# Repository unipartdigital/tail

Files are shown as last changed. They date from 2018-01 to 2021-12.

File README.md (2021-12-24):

# Tail
Tail - an indoor position system using UWB radio

# Description

Tail consists of tags, anchors and a server.

A tag is a battery-powered device which occasionally transmits a packet on UWB radio.

An anchor is an externally-powered device in a fixed location which acts as a bridge between UWB radio and the network on which the server resides.

The server sends and receives packets via the anchors, and is able to compute the location of each tag using multilateration.

A simpler mode of operation has also been developed whereby an anchor and a tag perform two-way communications to establish a distance between a tag and a single anchor.

# Status

Tail has been developed to a functional demo in a constrained test environment. It requires further development before it can be used in a production environment.

Unipart Digital is not currently developing this project past this stage.

# Video

Unipart Digital produced a video showing how the system works, and demonstrating it in action. The video is available here:

https://unipart.digital/images/projects/tail/tail-commercial.mp4

# Repositories

## tail
This repository is the monorepo that was used for the duration of the development project, so contains everything related to the tags - firmware, hardware, CAD etc,
various works on the anchor software as well as a number of scripts, utilities and other bits and pieces.

## dw1000
https://github.com/unipartdigital/dw1000

This contains hardware and drivers for a DW1000 interface card for a Raspberry Pi

## utrack-tail
https://github.com/unipartdigital/utrack-tail

This repository contains the standalone anchor code required for the two-way communications mode.

## tail-server
https://github.com/unipartdigital/tail-server

This repository contains the latest attempt at developing a multilaterating server for the one way ranging mode.

## tail-anchor-hardware
https://github.com/unipartdigital/tail-anchor-hardware

This repository contains the hardware for a standalone anchor

## tail-anchor-firmware
https://github.com/unipartdigital/tail-anchor-firmware

This repository contains the (as yet barely started) firmware for a standalone anchor

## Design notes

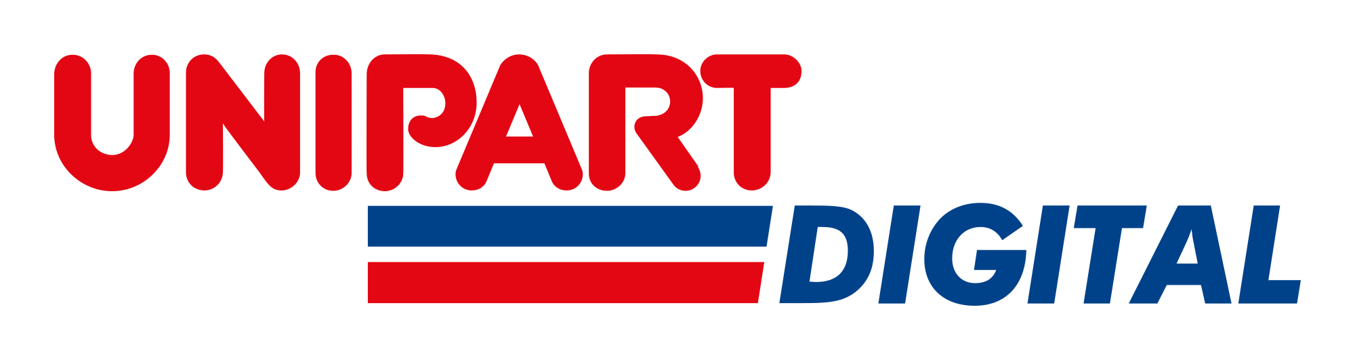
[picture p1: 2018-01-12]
circuit/v2b/Unipart_Digital_flat_RGB.png

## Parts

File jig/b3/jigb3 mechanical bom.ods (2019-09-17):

Quantity | 5
Item | Quantity per jig | Quantity total | URL
M2.5 hex nut | 8 | 40 | https://www.westfieldfasteners.co.uk/Metric-Nuts/Hex-Nut-M2.5-A2-Stainless.html
M2.5 screw 6mm | 8 | 40 | https://www.westfieldfasteners.co.uk/Bolts-Screws-Metric/Hex-Bolt-Full-Thread-M2.5x6-A2-Stainless.html
M2.5 dowel pin 20mm | 4 | 20 | https://www.westfieldfasteners.co.uk/Pins-and-Clips/Parallel-Pin-Dowel-Pin-2.5x20-A1-Stainless-Steel.html
M3 dowel pin 12mm | 2 | 10 | https://www.westfieldfasteners.co.uk/Pins-and-Clips/Parallel-Pin-Dowel-Pin-3x12-A1-Stainless-Steel.html

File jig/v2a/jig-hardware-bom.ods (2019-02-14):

Tail tag v2a jig BOM | Quantity | 10
Item | Quantity per jig | Quantity total | Supplier | Price | Price per | MOQ | Total price | Description
Jig PCB | 1 | 10 | GOC |  | 1 | 1 | 0
Pogo pins | 19 | 190 | Farnell | 1.75 | 1 | 1 | 332.5 | https://uk.farnell.com/harwin/p13-0123/probe-pointed-1-27mm-pitch/dp/9960104?ost=9960104
Toggle clamp GH-201B | 1 | 10 |  | 9.66 | 1 | 1 | 96.6 | https://www.goodhanduk.co.uk/Catalogue/Toggle-Clamps/Horizontal-Toggle-Clamps/Horizontal-Toggle-Clamp-Flat-Base-All-Arm-Types/Horizontal-Toggle-Clamp-Size-90K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 | Alternative with different dimensions: https://www.amazon.co.uk/IMAGINE-Holding-CapacityAntislip-Horizontal-Release/dp/B073Z9ZVGQ
8mm M2.5 screw | 8 | 80 |  | 2.28 | 80 | 80 | 2.28 | https://www.westfieldfasteners.co.uk/Bolts-Screws-Metric/Machine-Screw-Phillips-Pan-M2.5x8-A2-Stainless.html
M2.5 hex nut | 8 | 80 |  | 2.99 | 150 | 150 | 2.99 | https://www.westfieldfasteners.co.uk/Metric-Nuts/Hex-Nut-M2.5-A2-Stainless.html
M2.5 square nut | 4 | 40 |  | 0.1 | 1 | 1 | 4 | https://www.accu.co.uk/en/flat-square-nuts/21325-HFSN-M2-5-A2
12mm M5 bolt | 4 | 40 |  | 3.14 | 30 | 30 | 6.28 | https://www.westfieldfasteners.co.uk/Bolts-Screws-Metric/Machine-Screw-Phillips-Pan-M5x12-A2-Stainless.html
M5 square nut | 4 | 40 |  | 2.3 | 40 | 40 | 2.3 | https://www.westfieldfasteners.co.uk/Metric-Nuts/Square-Thin-Nut-M5-A2-Stainless.html
Total |  |  |  | 44.695 |  |  | 446.95

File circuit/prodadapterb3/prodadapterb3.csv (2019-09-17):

Source: | /home/gavan/Nextcloud/unipart/git/tail/circuit/prodadapterb3/prodadapterb3.sch
Date: | Tue 17 Sep 2019 14:27:01 BST
Tool: | Eeschema 4.0.7-e2-6376~61~ubuntu18.04.1
Generator: | /usr/lib/kicad/plugins/bom_csv_grouped_by_value.py
Component Count: | 8
Individual Components:
Item | Qty | Reference(s) | Value | LibPart | Footprint | Datasheet | MFR | MPN | SPN | SPR
 |  | J1 | Conn_02x20_Odd_Even | conn:Conn_02x20_Odd_Even | Pin_Headers:Pin_Header_Angled_2x20_Pitch2.54mm |  | Harting | 09 18 540 6903 | 1096897 | Farnell
 |  | J2 | Conn_02x05_Odd_Even | conn:Conn_02x05_Odd_Even | Pin_Headers:Pin_Header_Angled_2x05_Pitch1.27mm |  | Samtec | FTSH-105-01-L-D-RA-K | 2856878 | Farnell
 |  | J3 | Conn_01x02 | conn:Conn_01x02 | Pin_Headers:Pin_Header_Straight_1x02_Pitch2.54mm |  | Multicomp | 2211S-02G | 1593411 | Farnell
 |  | J4 | Conn_02x20_Odd_Even | conn:Conn_02x20_Odd_Even | Pin_Headers:Pin_Header_Angled_2x20_Pitch2.54mm |  | Harting | 09 18 540 6903 | 1096897 | Farnell
 |  | R1 | 3K9 | device:R | Resistors_THT:R_Axial_DIN0204_L3.6mm_D1.6mm_P5.08mm_Horizontal |  | Multicomp | MF12 3K9 | 9343156 | Farnell
 |  | R2 | 3K9 | device:R | Resistors_THT:R_Axial_DIN0204_L3.6mm_D1.6mm_P5.08mm_Horizontal |  | Multicomp | MF12 3K9 | 9343156 | Farnell
 |  | R3 | 3K9 | device:R | Resistors_THT:R_Axial_DIN0204_L3.6mm_D1.6mm_P5.08mm_Horizontal |  | Multicomp | MF12 3K9 | 9343156 | Farnell
 |  | U1 | 24LC128 | memory:24LC128 | Housings_DIP:DIP-8_W7.62mm |  | Microchip | 24LC128-I/P | 9757929 | Farnell
Collated Components:
Item | Qty | Reference(s) | Value | LibPart | Footprint | Datasheet | MFR | MPN | SPN | SPR
1 | 2 | J1, J4 | Conn_02x20_Odd_Even | conn:Conn_02x20_Odd_Even | Pin_Headers:Pin_Header_Angled_2x20_Pitch2.54mm |  | Harting | 09 18 540 6903 | 1096897 | Farnell
2 | 1 | J2 | Conn_02x05_Odd_Even | conn:Conn_02x05_Odd_Even | Pin_Headers:Pin_Header_Angled_2x05_Pitch1.27mm |  | Samtec | FTSH-105-01-L-D-RA-K | 2856878 | Farnell
3 | 1 | J3 | Conn_01x02 | conn:Conn_01x02 | Pin_Headers:Pin_Header_Straight_1x02_Pitch2.54mm |  | Multicomp | 2211S-02G | 1593411 | Farnell
4 | 3 | R1, R2, R3 | 3K9 | device:R | Resistors_THT:R_Axial_DIN0204_L3.6mm_D1.6mm_P5.08mm_Horizontal |  | Multicomp | MF12 3K9 | 9343156 | Farnell
5 | 1 | U1 | 24LC128 | memory:24LC128 | Housings_DIP:DIP-8_W7.62mm |  | Microchip | 24LC128-I/P | 9757929 | Farnell

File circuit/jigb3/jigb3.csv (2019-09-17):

Source: | /home/gavan/Nextcloud/unipart/git/tail/circuit/jigb3/jigb3.sch
Date: | Tue 17 Sep 2019 14:27:17 BST
Tool: | Eeschema 4.0.7-e2-6376~61~ubuntu18.04.1
Generator: | /usr/lib/kicad/plugins/bom_csv_grouped_by_value.py
Component Count: | 16
Individual Components:
Item | Qty | Reference(s) | Value | LibPart | Footprint | Datasheet | MFR | MPN | SPN | SPR
 |  | C1 | 2.2u | device:C_Small | Capacitors_THT:CP_Radial_D5.0mm_P2.00mm |  | Multicomp | MCRH100V225M5X11 | 1902943 | Farnell
 |  | C2 | 100n | device:C_Small | Capacitors_THT:C_Disc_D5.0mm_W2.5mm_P5.00mm |  | Vishay | K104K15X7RF53H5 | 1141777 | Farnell
 |  | C3 | 2.2u | device:C_Small | Capacitors_THT:CP_Radial_D5.0mm_P2.00mm |  | Multicomp | MCRH100V225M5X11 | 1902943 | Farnell
 |  | J1 | Conn_01x05 | conn:Conn_01x05 | Pin_Headers:Pin_Header_Angled_1x05_Pitch2.54mm |  | Wurth | 61300511021 | 2356179 | Farnell
 |  | J2 | Conn_01x05 | conn:Conn_01x05 | Pin_Headers:Pin_Header_Angled_1x05_Pitch2.54mm |  | Wurth | 61300511021 | 2356179 | Farnell
 |  | J3 | Conn_01x03 | conn:Conn_01x03 | Pin_Headers:Pin_Header_Angled_1x03_Pitch2.54mm |  | Wurth | 61300311021 | 2356177 | Farnell
 |  | J4 | Conn_02x05_Odd_Even | conn:Conn_02x05_Odd_Even | Pin_Headers:Pin_Header_Angled_2x05_Pitch1.27mm |  | Samtec | FTSH-105-01-L-D-RA-K | 2856878 | Farnell
 |  | J5 | Conn_01x01 | conn:Conn_01x01 | jigb3:P70-2200045 |  | Harwin | P70-2200045 | 2664890 | Farnell
 |  | J6 | Conn_01x01 | conn:Conn_01x01 | jigb3:P70-2200045 |  | Harwin | P70-2200045 | 2664890 | Farnell
 |  | J7 | Conn_01x01 | conn:Conn_01x01 | jigb3:P70-2200045 |  | Harwin | P70-2200045 | 2664890 | Farnell
 |  | J8 | Conn_01x01 | conn:Conn_01x01 | jigb3:P70-2200045 |  | Harwin | P70-2200045 | 2664890 | Farnell
 |  | J9 | Conn_01x01 | conn:Conn_01x01 | jigb3:P70-2200045 |  | Harwin | P70-2200045 | 2664890 | Farnell
 |  | J10 | Conn_01x01 | conn:Conn_01x01 | jigb3:P70-2200045 |  | Harwin | P70-2200045 | 2664890 | Farnell
 |  | J11 | Conn_02x20_Odd_Even | conn:Conn_02x20_Odd_Even | Pin_Headers:Pin_Header_Straight_2x20_Pitch2.54mm |  | Multicomp | 2213S-40G | 2725179 | Farnell
 |  | R1 | 100K | device:R | Resistors_THT:R_Axial_DIN0204_L3.6mm_D1.6mm_P5.08mm_Horizontal |  | Multicomp | MF12 100K | 9342427 | Farnell
 |  | U1 | MAX882 | regul:MAX882 | Housings_DIP:DIP-8_W7.62mm |  | Maxim | MAX882CPA+ | 2517079 | Farnell
Collated Components:
Item | Qty | Reference(s) | Value | LibPart | Footprint | Datasheet | MFR | MPN | SPN | SPR
1 | 2 | C1, C3 | 2.2u | device:C_Small | Capacitors_THT:CP_Radial_D5.0mm_P2.00mm |  | Multicomp | MCRH100V225M5X11 | 1902943 | Farnell
2 | 1 | C2 | 100n | device:C_Small | Capacitors_THT:C_Disc_D5.0mm_W2.5mm_P5.00mm |  | Vishay | K104K15X7RF53H5 | 1141777 | Farnell
3 | 2 | J1, J2 | Conn_01x05 | conn:Conn_01x05 | Pin_Headers:Pin_Header_Angled_1x05_Pitch2.54mm |  | Wurth | 61300511021 | 2356179 | Farnell
4 | 1 | J3 | Conn_01x03 | conn:Conn_01x03 | Pin_Headers:Pin_Header_Angled_1x03_Pitch2.54mm |  | Wurth | 61300311021 | 2356177 | Farnell
5 | 1 | J4 | Conn_02x05_Odd_Even | conn:Conn_02x05_Odd_Even | Pin_Headers:Pin_Header_Angled_2x05_Pitch1.27mm |  | Samtec | FTSH-105-01-L-D-RA-K | 2856878 | Farnell
6 | 6 | J5, J6, J7, J8, J9, J10 | Conn_01x01 | conn:Conn_01x01 | jigb3:P70-2200045 |  | Harwin | P70-2200045 | 2664890 | Farnell
7 | 1 | J11 | Conn_02x20_Odd_Even | conn:Conn_02x20_Odd_Even | Pin_Headers:Pin_Header_Straight_2x20_Pitch2.54mm |  | Multicomp | 2213S-40G | 2725179 | Farnell
8 | 1 | R1 | 100K | device:R | Resistors_THT:R_Axial_DIN0204_L3.6mm_D1.6mm_P5.08mm_Horizontal |  | Multicomp | MF12 100K | 9342427 | Farnell
9 | 1 | U1 | MAX882 | regul:MAX882 | Housings_DIP:DIP-8_W7.62mm |  | Maxim | MAX882CPA+ | 2517079 | Farnell

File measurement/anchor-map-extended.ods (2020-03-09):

 | 1 | 2 | 3 | 4 | 5 | 6 | 7 | 8 | 9 | 10 | 11 | 12 | 13 | 14 | 15
1 | x | - | - | - | - | - | - | - | - | - | 324 | 395 | 557 | 740 | 935
2 | x | x | - | - | - | - | - | - | - | - | 386 | 291 | 309 | 438 | 614
3 | x | x | x | - | - | - | - | - | - | -
4 | x | x | x | x | - | - | - | - | - | - | 753 | 588 | 400 | 250 | 234
5 | x | x | x | x | x | - | - | - | - | -
6 | x | x | x | x | x | x | - | - | - | -
7 | x | x | x | x | x | x | x | - | - | - | 312 | 357 | 486 | 664 | 855
8 | x | x | x | x | x | x | x | x | - | -
9 | x | x | x | x | x | x | x | x | x | - | 559 | 411 | 277 | 282 | 413
10 | x | x | x | x | x | x | x | x | x | x | 893 | 728 | 525 | 340 | 211
11 | x | x | x | x | x | x | x | x | x | x | x
12 | x | x | x | x | x | x | x | x | x | x | x | x
13 | x | x | x | x | x | x | x | x | x | x | x | x | x
14 | x | x | x | x | x | x | x | x | x | x | x | x | x | x
15 | x | x | x | x | x | x | x | x | x | x | x | x | x | x | x
Z |  |  |  |  |  |  |  |  |  |  | 4.7 | 4.7 | 4.7 | 4.7 | 4.7
 | X | Y | Z
11 | 0.33489371 | 3.13808962 | -0.047
12 | 2.06095082 | 2.96326638 | -0.047
13 | 4.16335929 | 2.62943822 | -0.047
14 | 6.26712033 | 2.38474151 | -0.047
15 | 8.35542711 | 2.12059253 | -0.047

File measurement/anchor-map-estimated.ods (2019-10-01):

0 | 632.03924831 | 32 | 1 |  | 1 | 2 | 3 | 4 | 5 | 6 | 7 | 8 | 9 | 10
329.55736086 | 557.70306928 | 33 | 2 (top) | 1 | x | 337.83860290054 | 350.682878451111 | 800.550696320505 | 1030.33437301795 | 507.674512944963 | 632.093616925006 | 803.938136224154 | 800.040606772778 | 1074.35830753595
329.94077707 | 557.09443618 | 124.2 | 3 (bottom) | 2 | x | x | 91.2028368102687 | 462.917088328823 | 711.515809491833 | 542.535538862879 | 643.748108199432 | 666.542603932412 | 583.294673321986 | 774.496596643959
776.03914733 | 435.45743534 | 31.5 | 4 | 3 | x | x | x | 471.585205367999 | 704.957560625813 | 534.565046775072 | 650.264912876859 | 660.185648927858 | 589.577311100258 | 779.208388487231
907.27560286 | 152.55813223 | 124.4 | 5 | 4 | x | x | x | x | 325.400419422289 | 833.719350411966 | 882.858855017837 | 715.212634128539 | 527.945932798777 | 440.341330083461
4.73432517999999 | 132.82971589 | 124.2 | 6 | 5 | x | x | x | x | x | 902.756893259493 | 916.951593112388 | 646.259779620162 | 460.117212571123 | 176.38796414993
8.04544299999998 | 0 | 30 | 7 | 6 | x | x | x | x | x | x | 162.875218878244 | 388.591550769894 | 507.145152883847 | 882.332637271155
313.65290155 | -102.87988617 | 120.5 | 8 | 7 | x | x | x | x | x | x | x | 334.918556816045 | 476.438345385502 | 865.045208041609
484.44593583 | -4.65052524 | 33.8 | 9 | 8 | x | x | x | x | x | x | x | x | 215.258351538995 | 576.653727452348
873.0666435 | 5.94008765 | 32.5 | 10 | 9 | x | x | x | x | x | x | x | x | x | 388.767161050567
 |  |  |  | 10 | x | x | x | x | x | x | x | x | x | x
 |  |  |  |  | 1 | 2 | 3 | 4 | 5 | 6 | 7 | 8 | 9 | 10
 |  |  |  | 1 | x | 338 | 351 | 800 | 1030 | 507 | 632 | 804 | 800 | 1075
 |  |  |  | 2 | x | x | 91 | 463 | 712 | 542 | 644 | 667 | 583 | 774
 |  |  |  | 3 | x | x | x | 472 | 705 | 535 | 650 | 660 | 590 | 779
 |  |  |  | 4 | x | x | x | x | 325 | 834 | 883 | 715 | 351 | 440
 |  |  |  | 5 | x | x | x | x | x | 903 | 917 | 646 | 460 | 176
 |  |  |  | 6 | x | x | x | x | x | x | 162 | 388 | 507 | 882
 |  |  |  | 7 | x | x | x | x | x | x | x | ************** | 476 | 865
 |  |  |  | 8 | x | x | x | x | x | x | x | x | 316 | 577
 |  |  |  | 9 | x | x | x | x | x | x | x | x | x | 388
 |  |  |  | 10 | x | x | x | x | x | x | x | x | x | x
 |  |  |  | cm | 1 | 2 | 3 | 4 | 5 | 6 | 7 | 8 | 9 | 10
 |  |  |  | 1 | x | 0.16139709946043 | 0.317121548889418 | -0.55069632050504 | -0.334373017953112 | -0.674512944962601 | -0.09361692500579 | 0.061863775846064 | -0.040606772777892 | 0.641692464049129
 |  |  |  | 2 | x | x | -0.202836810268721 | 0.082911671177215 | 0.484190508166535 | -0.53553886287898 | 0.251891800567819 | 0.457396067588093 | -0.294673321985556 | -0.49659664395881
 |  |  |  | 3 | x | x | x | 0.414794632000564 | 0.042439374187325 | 0.434953224928108 | -0.264912876859057 | -0.185648927857756 | 0.422688899742298 | -0.20838848723065
 |  |  |  | 4 | x | x | x | x | -0.400419422288564 | 0.280649588033612 | 0.141144982163155 | -0.212634128539207 | -176.945932798777 | -0.34133008346123
 |  |  |  | 5 | x | x | x | x | x | 0.243106740507301 | 0.048406887611577 | -0.259779620161794 | -0.117212571123446 | -0.387964149929985
 |  |  |  | 6 | x | x | x | x | x | x | -0.875218878244453 | -0.591550769894013 | -0.145152883846606 | -0.332637271154908
 |  |  |  | 7 | x | x | x | x | x | x | x | ************** | -0.438345385501918 | -0.045208041609271
 |  |  |  | 8 | x | x | x | x | x | x | x | x | 100.741648461005 | 0.34627254765212
 |  |  |  | 9 | x | x | x | x | x | x | x | x | x | -0.767161050566983
 |  |  |  | 10 | x | x | x | x | x | x | x | x | x | x
 |  |  |  |  |  |  |  |  | Original estimates |  |  | Removed 4/9 |  |  | Removed 4/9 and 7/9 |  | Normalised
 |  |  |  |  |  |  |  |  | -549.92060933 | 554.79006164 |  | -453.53371699 | 673.8855102 |  | -485.77448252 | 630.85439371 | 0 | 632.03924831
 |  |  |  |  |  |  |  |  | -216.69719363 | 509.12302366 |  | -129.39312323 | 579.41924456 |  | -156.21712166 | 556.51821468 | 329.55736086 | 557.70306928
 |  |  |  |  |  |  |  |  | -216.28381488 | 508.53831533 |  | -129.0531305 | 578.78592534 |  | -155.83370545 | 555.90958158 | 329.94077707 | 557.09443618
 |  |  |  |  |  |  |  |  | 239.01845486 | 399.2983762 |  | 308.55206086 | 428.17610248 |  | 290.26466481 | 434.27258074 | 776.03914733 | 435.45743534
 |  |  |  |  |  |  |  |  | 394.45296138 | 152.2766373 |  | 422.31680235 | 139.00937021 |  | 421.50112034 | 151.37327763 | 907.27560286 | 152.55813223
 |  |  |  |  |  |  |  |  | -503.95725213 | 53.99389318 |  | -479.57394355 | 174.9388591 |  | -481.04015734 | 131.64486129 | 4.73432517999999 | 132.82971589
 |  |  |  |  |  |  |  |  | -488.90319769 | -77.97627345 |  | -484.17633545 | 41.92596162 |  | -477.72903952 | -1.1848546 | 8.04544299999998 | 0
 |  |  |  |  |  |  |  |  | -184.45730836 | -156.03790622 |  | -190.33885462 | -79.95536936 |  | -172.12158097 | -104.06474077 | 313.65290155 | -102.87988617
 |  |  |  |  |  |  |  |  | 11.95845782 | -2.52522182 |  | -2.44477591 | 13.47578202 |  | -1.32854669 | -5.83537984 | 484.44593583 | -4.65052524
 |  |  |  |  |  |  |  |  | 371.10605914 | -0.83738859 |  | 378.88551441 | -5.52773253 |  | 387.29216098 | 4.75523305 | 873.0666435 | 5.94008765

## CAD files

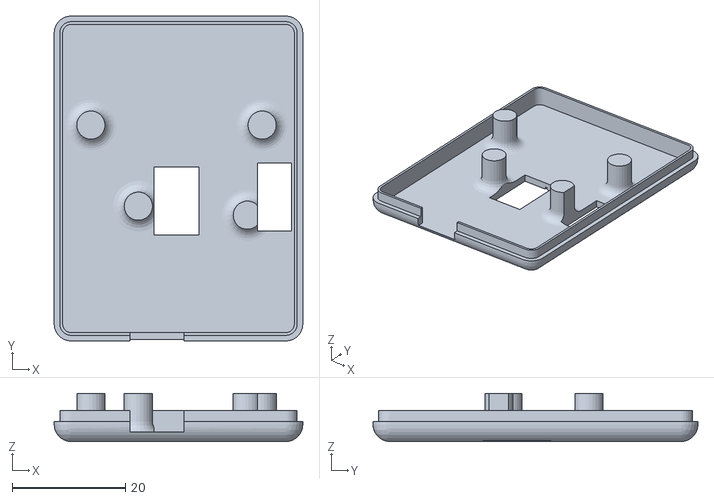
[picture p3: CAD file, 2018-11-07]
case/v2/case-lid.stl
44.0 x 57.5 x 8.50

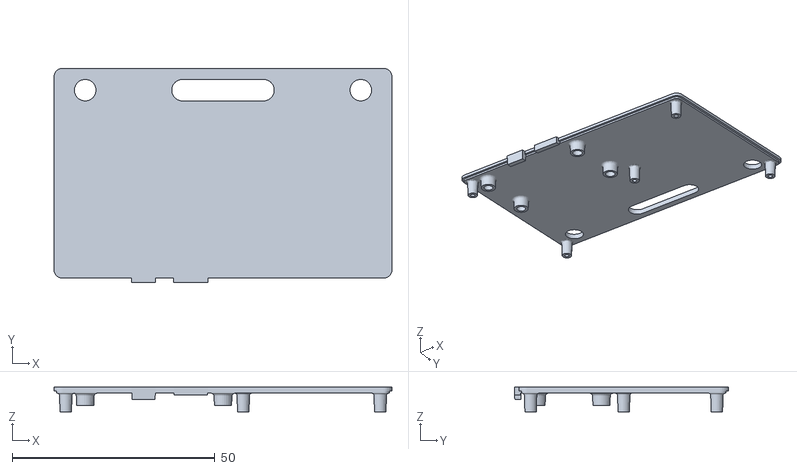
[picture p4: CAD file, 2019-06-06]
case/v2a/case-lid-lip2.stl
83.4 x 52.9 x 6.10

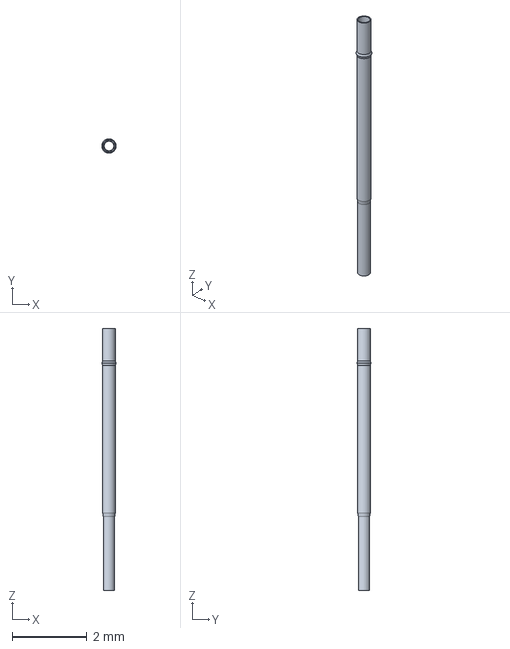
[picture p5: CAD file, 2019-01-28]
circuit/jig2a/s13-503.fcstd
0.382 x 0.382 x 6.99 mm

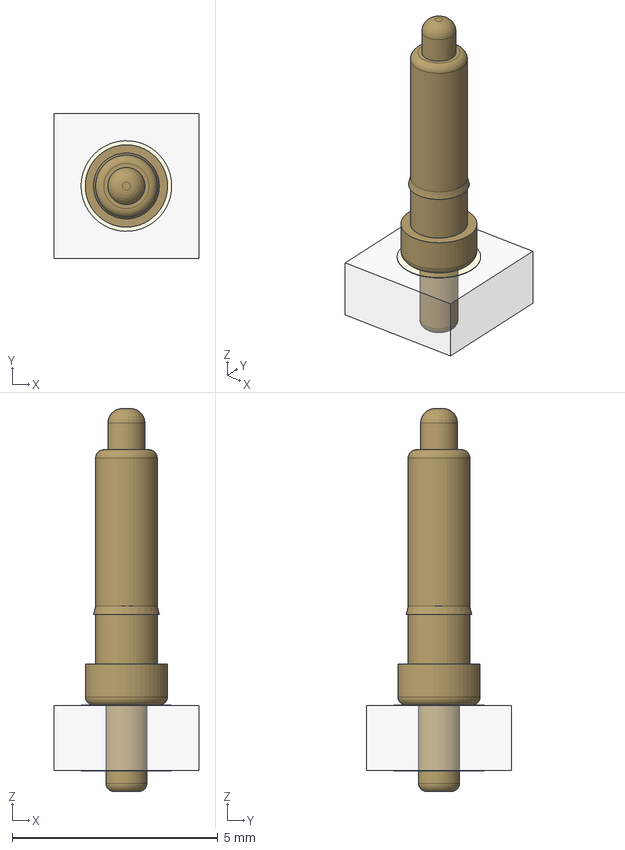
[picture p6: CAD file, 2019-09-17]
circuit/jigb3/pogopin.FCStd
3.51 x 3.52 x 9.30 mm
TopPads
BotPads
PTHs
Pcb

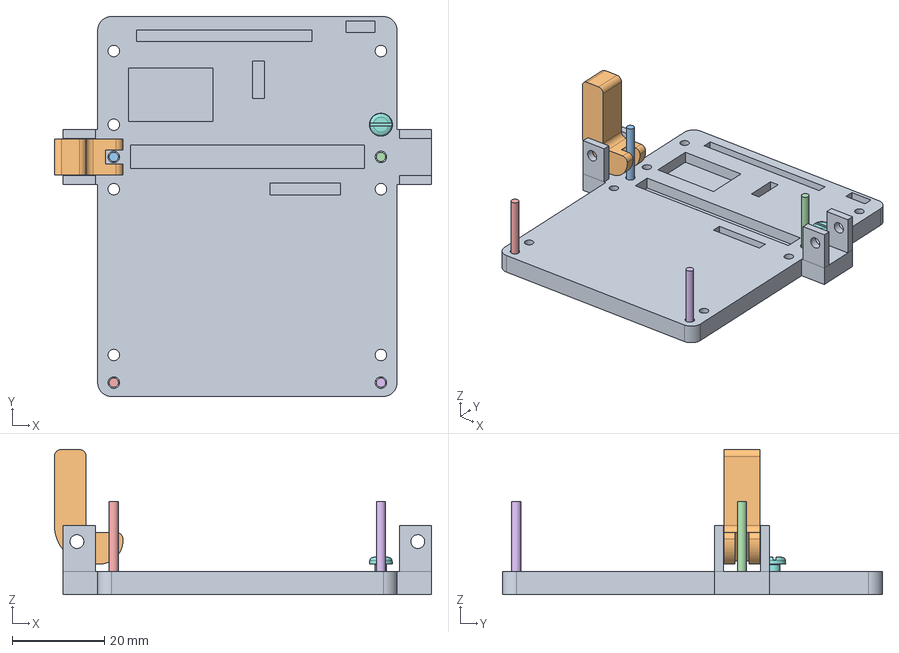
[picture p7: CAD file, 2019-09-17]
jig/b3/b3jig.FCStd
81.9 x 82.5 x 31.5 mm
JigBody
LeftLever
M2.5x20.0-ScrewTap
M2.5x20.0-ScrewTap004
M2.5x20.0-ScrewTap006
M2.5x20.0-ScrewTap007
M2.5-Nut
M2.5x6-Screw

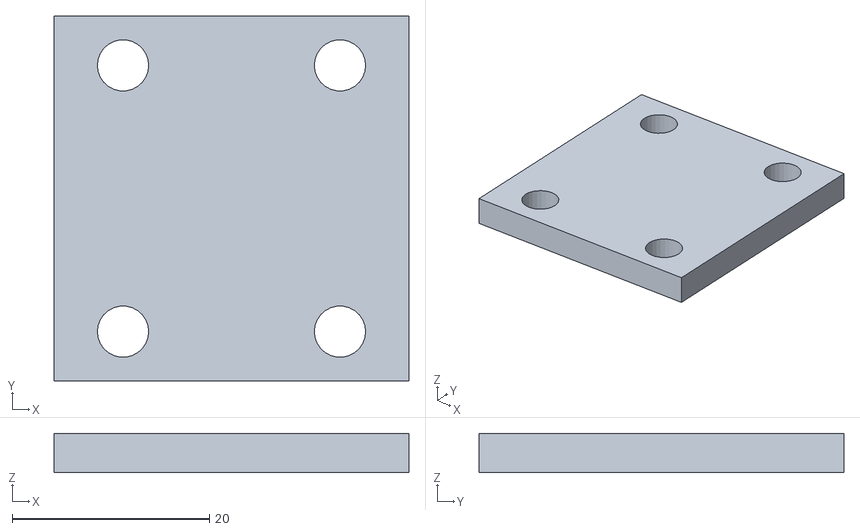
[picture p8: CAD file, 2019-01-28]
jig/v2a/jig-spacer.stl
36.0 x 37.0 x 4.00

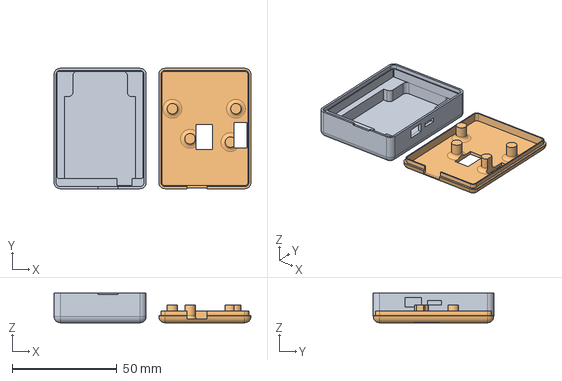
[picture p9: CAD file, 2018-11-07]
case/v2/case.fcstd
94.0 x 57.5 x 14.1 mm
Lid

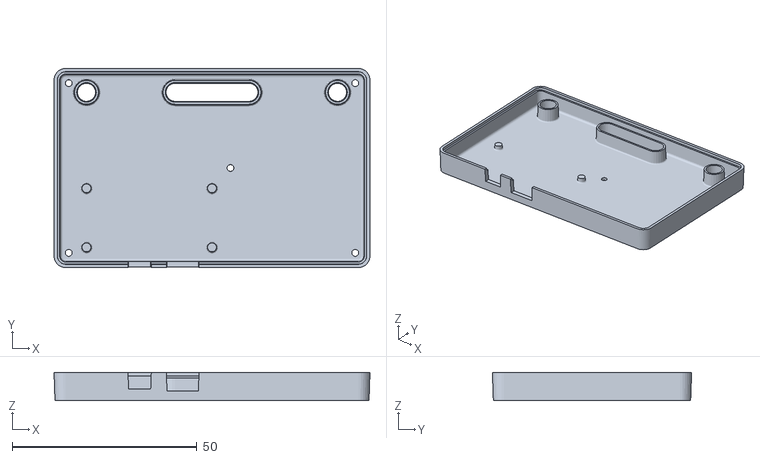
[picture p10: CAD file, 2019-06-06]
case/v2a/case-base-lip2.stl
85.6 x 54.0 x 7.60

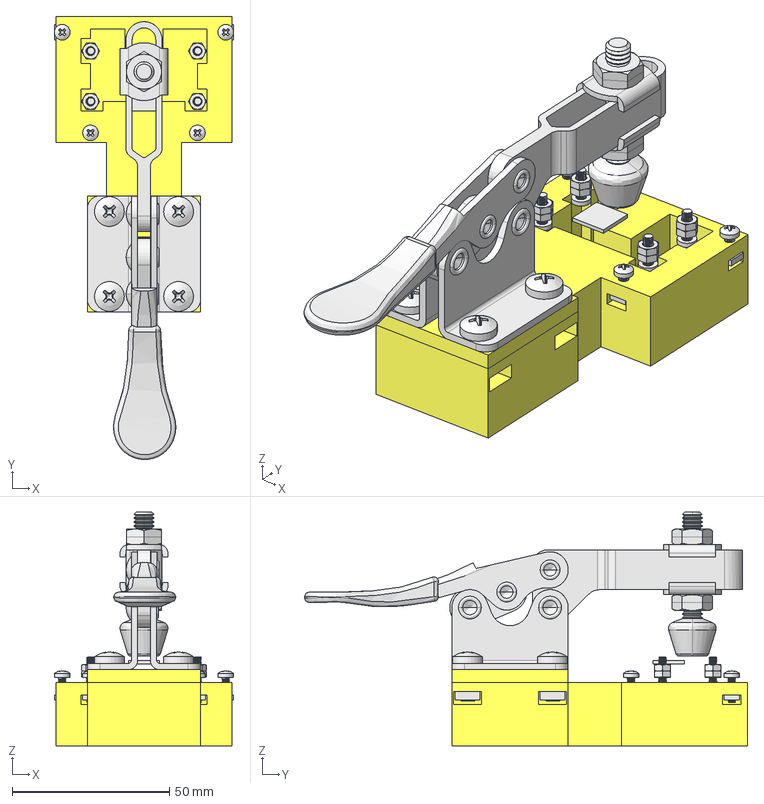
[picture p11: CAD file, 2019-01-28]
jig/v2a/jig.fcstd
57.0 x 140.8 x 74.4 mm
ClampCompound
M2.5x8-Screw230
M2.5x8-Screw
M2.5x8-Screw229
M2.5x8-Screw228
M2.5x8-Screw231
M2.5x8-Screw226
M2.5x8-Screw227
M2.5x8-Screw232
M2.5-Nut278
M2.5-Nut276
M2.5-Nut277
M2.5-Nut279
M2.5-Nut284
M2.5-Nut282
M2.5-Nut274
M2.5-Nut281
M2.5-Nut280
M2.5-Nut283
M2.5-Nut275
M2.5-Nut
M5x12-Screw412
M5x12-Screw
M5x12-Screw413
M5x12-Screw411
M5-Nut
M5-Nut350
M5-Nut349
M5-Nut348
ClampSpacer
TailCube

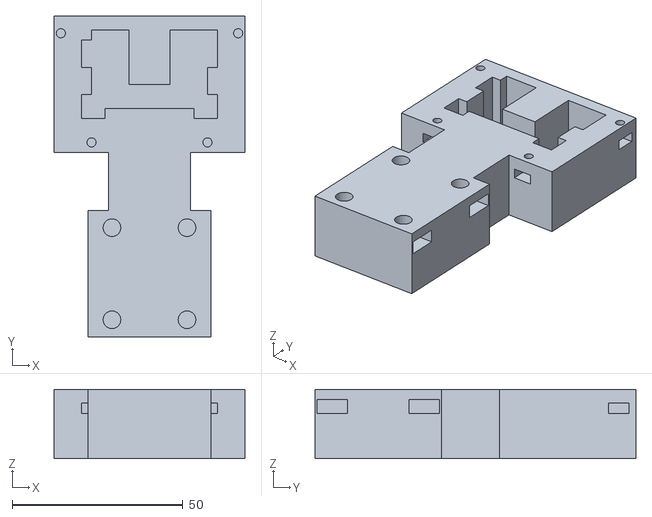
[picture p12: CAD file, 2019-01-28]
jig/v2a/jig-body.stl
56.0 x 94.0 x 20.2

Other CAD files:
case/v2/tail-logo-simplified-scaled.dxf
case/v2a/case.FCStd
case/v2/case.stl

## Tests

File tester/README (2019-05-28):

Things to install:

sudo apt install libgles2-mesa-dev

sudo -H pip3 install cython
sudo -H pip3 install kivy
sudo -H pip3 install InstrumentKit
sudo -H pip3 install gpiozero
sudo -H pip3 install netaddr

sudo apt isntall libsdl1.2-dev

sudo apt-get install libsdl2-dev libsdl2-image-dev libsdl2-mixer-dev libsdl2-ttf-dev \
   pkg-config libgl1-mesa-dev libgles2-mesa-dev \
   python-setuptools libgstreamer1.0-dev git-core \
   gstreamer1.0-plugins-{bad,base,good,ugly} \
   gstreamer1.0-{omx,alsa} python-dev libmtdev-dev \
   xclip xsel

sudo apt-get update&&sudo apt-get install libsdl-dev libsdl-image1.2-dev libsdl-mixer1.2-dev libsdl-ttf2.0-dev 
sudo apt-get install libsmpeg-dev libportmidi-dev libavformat-dev libswscale-dev
sudo apt-get install python3-dev python3-numpy

sudo -H pip3 install pygame

sudo -H pip3 install pigpio

#sudo apt install openocd

# Raspbian Stretch has too old an openocd. We need at least 0.10.0.

sudo apt install debhelper libftdi1-dev libusb-1.0-0-dev libusb-dev
sudo apt install texinfo texlive libhidapi-dev
sudo apt install libjim-dev pkg-config

# Now download and untar openocd-0.10.0

cd openocd-0.10.0
./configure -disable-werror \
	--disable-internal-jimtcl \
	--disable-internal-libjaylink \
	\
	--enable-dummy \
	--enable-ep93xx \
	--enable-at91rm9200 \
	--enable-usbprog \
	--enable-vsllink \
	--enable-rlink \
	--enable-ulink \
	--enable-arm-jtag-ew \
	--enable-buspirate \
	--enable-osbdm \
	--enable-opendous \
	--enable-remote-bitbang \
	--enable-bcm2835gpio \
	--enable-sysfsgpio \
	--enable-parport \
	--enable-parport_ppdev \
	--enable-gw16012 \
	--enable-amtjtagaccel \
	--enable-ftdi \
	--enable-stlink \
	--enable-ti-icdi

make
sudo make install

udev things for serial ports
sudo cp tail-tester.rules /etc/udev/rules.d
sudo udevadm control --reload

mkdir ~/firmware

Put some files in the directory

Add to [input] section of .kivy/config.ini

mouse = mouse
mtdev_%(name)s = probesysfs,provider=mtdev
hid_%(name)s = probesysfs,provider=hidinput

Create tester.ini:

[Tester]
FrequencyCounter: /dev/ttyStf930
Multimeter:       /dev/ttySgdm8341
GPSDO:            /dev/hidraw-gpsdo

Disable lightdm otherwise touch screen presses also end up in X, which
randomly launches unrelated applications while you're not looking

Depending on how you're starting the tester, you may want to do this permanently.

sudo systemctl stop lightdm
sudo systemctl disable lightdm

If you want a desktop icon that will launch the tester:

cp tester.desktop ~/Desktop/

Remove console/serial0,115200 from /boot/cmdline.txt
Use raspi-config to enable the serial port but disable a login prompt on the serial port

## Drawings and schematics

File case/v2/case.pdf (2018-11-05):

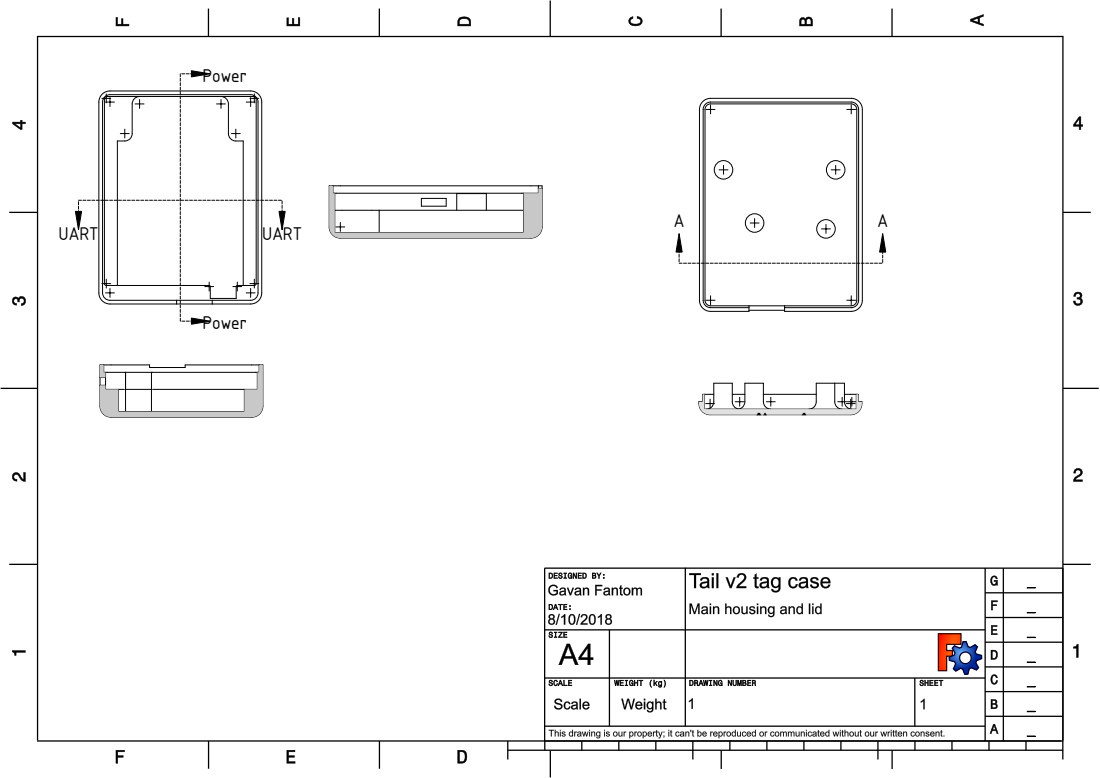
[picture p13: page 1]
er Power

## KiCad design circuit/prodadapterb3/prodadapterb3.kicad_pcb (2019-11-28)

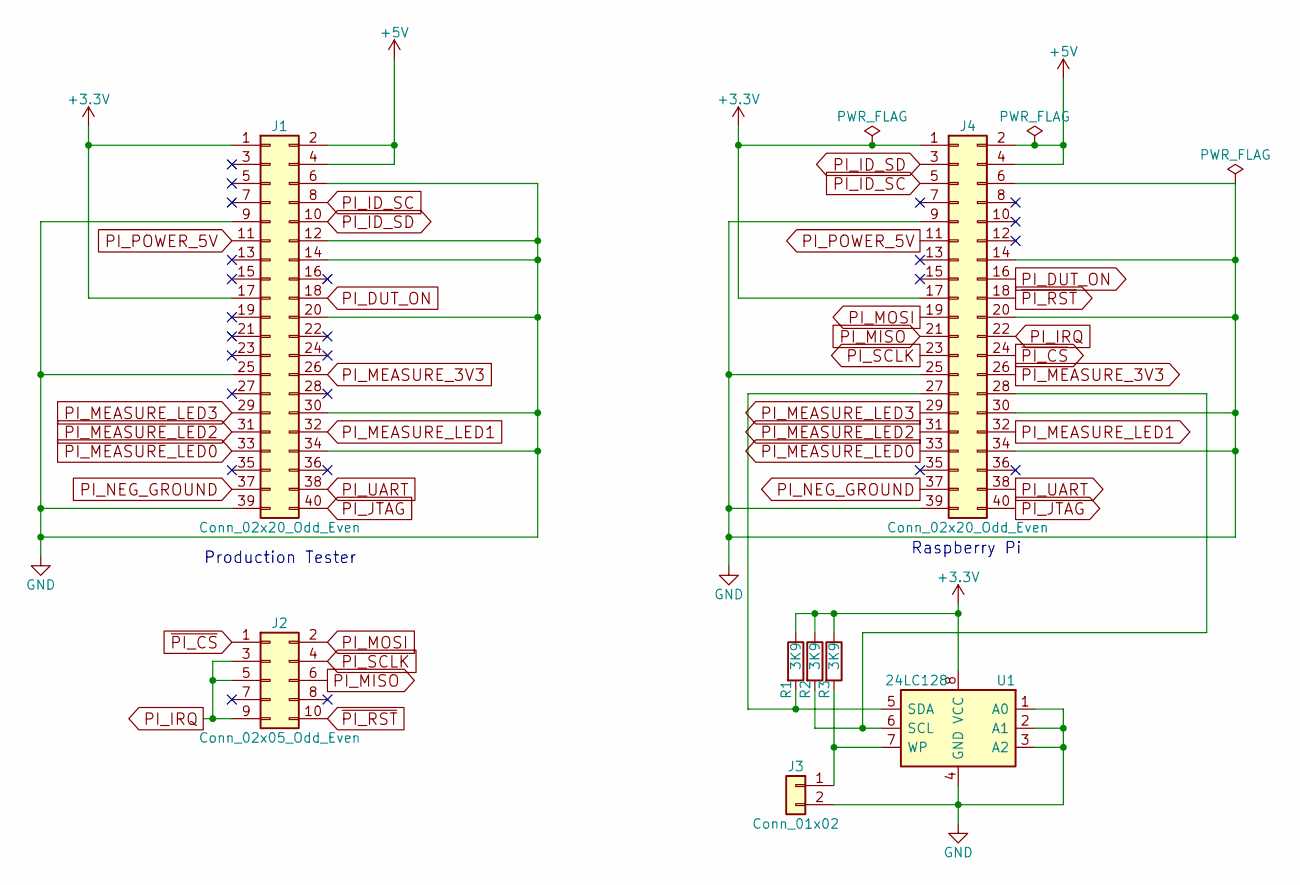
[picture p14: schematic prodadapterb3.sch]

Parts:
J1, J4: Conn_02x20_Odd_Even; Pin_Header_Angled_2x20_Pitch2.54mm; MPN 09 18 540 6903
J2: Conn_02x05_Odd_Even; Pin_Header_Angled_2x05_Pitch1.27mm; MPN FTSH-105-01-L-D-RA-K
J3: Conn_01x02; Pin_Header_Straight_1x02_Pitch2.54mm; MPN 2211S-02G
R1, R2, R3: 3K9; R_Axial_DIN0204_L3.6mm_D1.6mm_P5.08mm_Horizontal; MPN MF12 3K9
U1: 24LC128; DIP-8_W7.62mm; MPN 24LC128-I/P

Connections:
+3V3: J1.1, J1.17, J4.1, J4.17, R1.1, R2.1, R3.1, U1.8 (VCC)
+5V: J1.2, J1.4, J4.2, J4.4
GND: J1.6, J1.9, J1.12, J1.14, J1.20, J1.25, J1.30, J1.34, J1.39, J3.2, J4.6, J4.9, J4.14, J4.20, J4.25, J4.30, J4.34, J4.39, U1.1 (A0), U1.2 (A1), U1.3 (A2), U1.4 (GND)
unnamed: J3.1, R3.2, U1.7 (WP)
unnamed: J4.27, R1.2, U1.5 (SDA)
unnamed: J4.28, R2.2, U1.6 (SCL)
PI_DUT_ON: J1.18, J4.16
PI_ID_SC: J1.8, J4.5
PI_ID_SD: J1.10, J4.3
PI_IRQ: J2.3, J2.5, J2.9, J4.22
PI_JTAG: J1.40, J4.40
PI_MEASURE_3V3: J1.26, J4.26
PI_MEASURE_LED0: J1.33, J4.33
PI_MEASURE_LED1: J1.32, J4.32
PI_MEASURE_LED2: J1.31, J4.31
PI_MEASURE_LED3: J1.29, J4.29
PI_MISO: J2.6, J4.21
PI_MOSI: J2.2, J4.19
PI_NEG_GROUND: J1.37, J4.37
PI_POWER_5V: J1.11, J4.11
PI_SCLK: J2.4, J4.23
PI_UART: J1.38, J4.38
~PI_CS: J2.1, J4.24
~PI_RST: J2.10, J4.18

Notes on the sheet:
Raspberry Pi
Production Tester

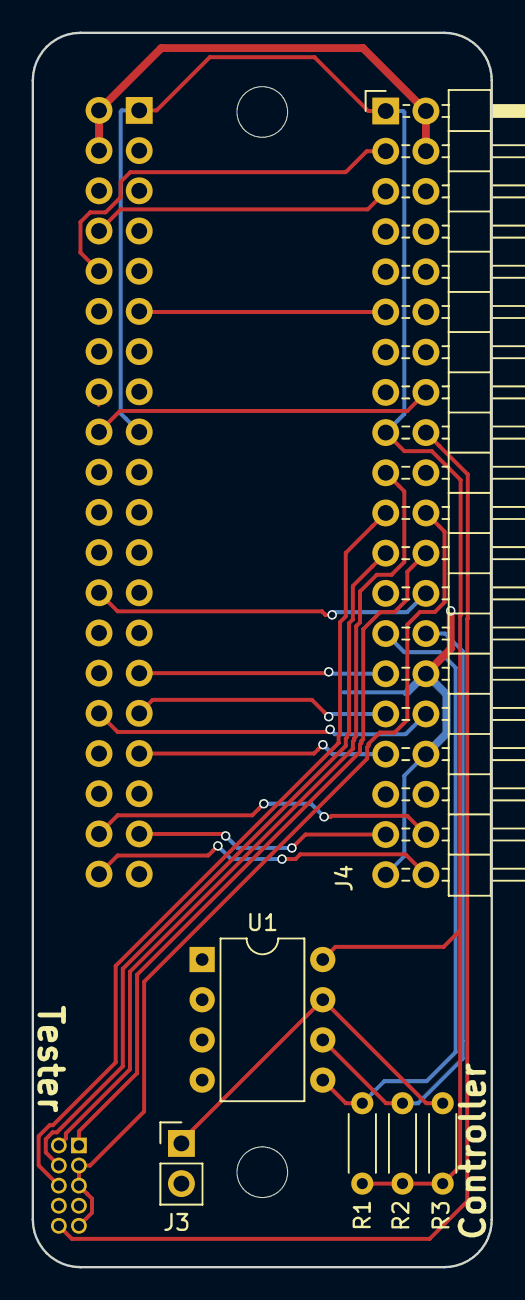
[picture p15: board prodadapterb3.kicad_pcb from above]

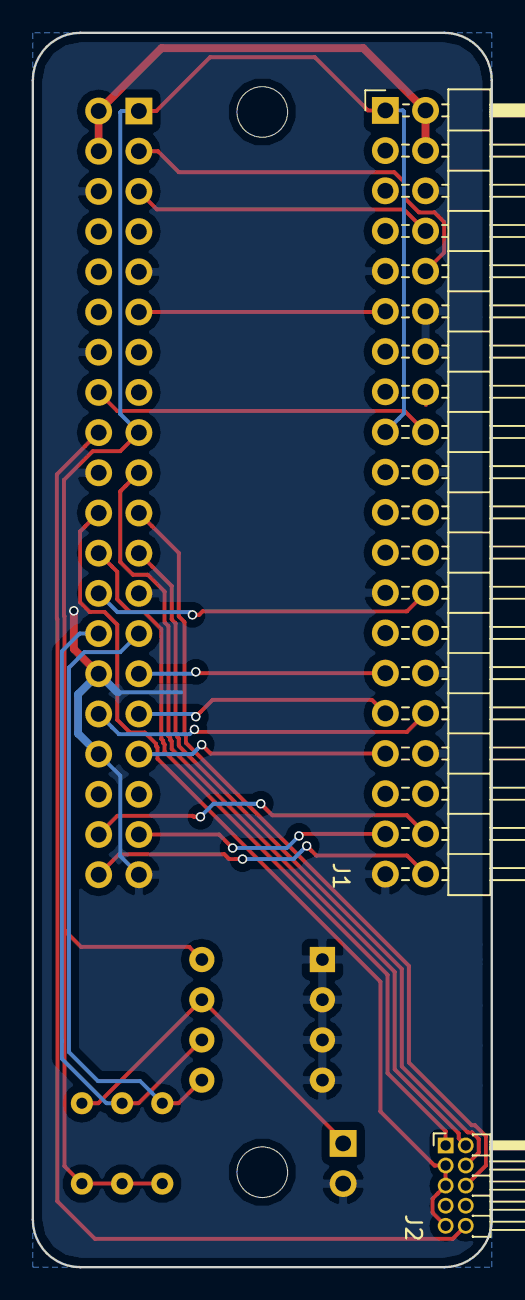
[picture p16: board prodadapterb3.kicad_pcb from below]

Board: 2 copper layers, 29.0 x 78.0 mm, 8 parts (2 on the bottom side), 24 nets.

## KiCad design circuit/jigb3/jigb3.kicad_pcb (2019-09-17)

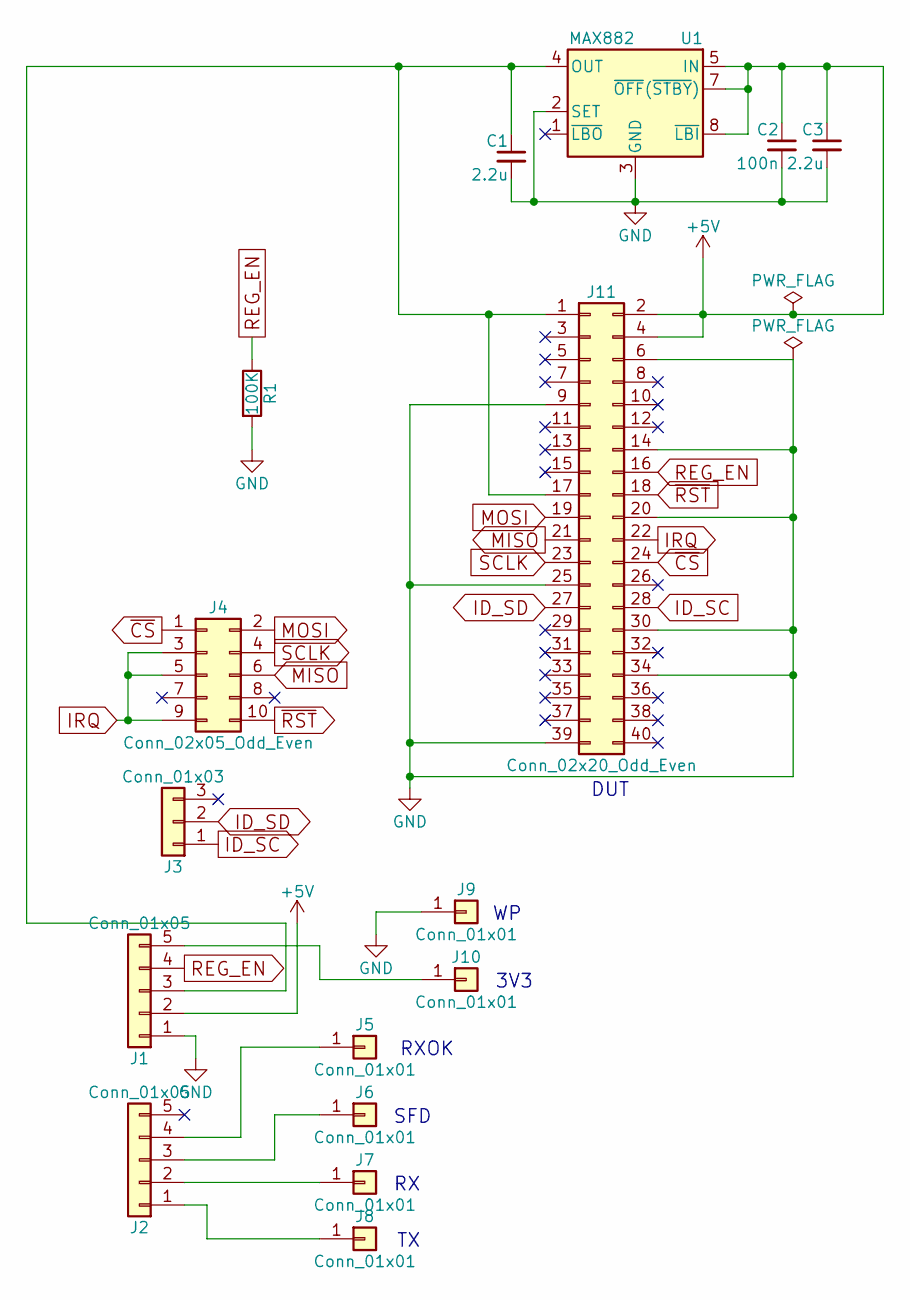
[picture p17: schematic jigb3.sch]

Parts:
C1, C3: 2.2u; CP_Radial_D5.0mm_P2.00mm; MPN MCRH100V225M5X11
C2: 100n; C_Disc_D5.0mm_W2.5mm_P5.00mm; MPN K104K15X7RF53H5
J1, J2: Conn_01x05; Pin_Header_Angled_1x05_Pitch2.54mm; MPN 61300511021
J3: Conn_01x03; Pin_Header_Angled_1x03_Pitch2.54mm; MPN 61300311021
J4: Conn_02x05_Odd_Even; Pin_Header_Angled_2x05_Pitch1.27mm; MPN FTSH-105-01-L-D-RA-K
J5, J6, J7, J8, J9, J10: Conn_01x01; P70-2200045; MPN P70-2200045
J11: Conn_02x20_Odd_Even; Pin_Header_Straight_2x20_Pitch2.54mm; MPN 2213S-40G
R1: 100K; R_Axial_DIN0204_L3.6mm_D1.6mm_P5.08mm_Horizontal; MPN MF12 100K
U1: MAX882; DIP-8_W7.62mm; MPN MAX882CPA+

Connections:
+5V: C2.1, C3.1, J1.2, J11.2, J11.4, U1.5 (IN), U1.7 (~OFF~(~STBY~)), U1.8 (~LBI)
GND: C1.2, C2.2, C3.2, J1.1, J9.1, J11.6, J11.9, J11.14, J11.20, J11.25, J11.30, J11.34, J11.39, R1.2, U1.2 (SET), U1.3 (GND), U1.6 (GND)
ID_SC: J3.1, J11.28
ID_SD: J3.2, J11.27
IRQ: J4.3, J4.5, J4.9, J11.22
MISO: J4.6, J11.21
MOSI: J4.2, J11.19
unnamed: C1.1, J1.3, J11.1, J11.17, U1.4 (OUT)
unnamed: J1.5, J10.1
unnamed: J2.1, J8.1
unnamed: J2.2, J7.1
unnamed: J2.3, J6.1
unnamed: J2.4, J5.1
REG_EN: J1.4, J11.16, R1.1
SCLK: J4.4, J11.23
~CS: J4.1, J11.24
~RST: J4.10, J11.18

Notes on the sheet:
DUT
3V3
RXOK
SFD

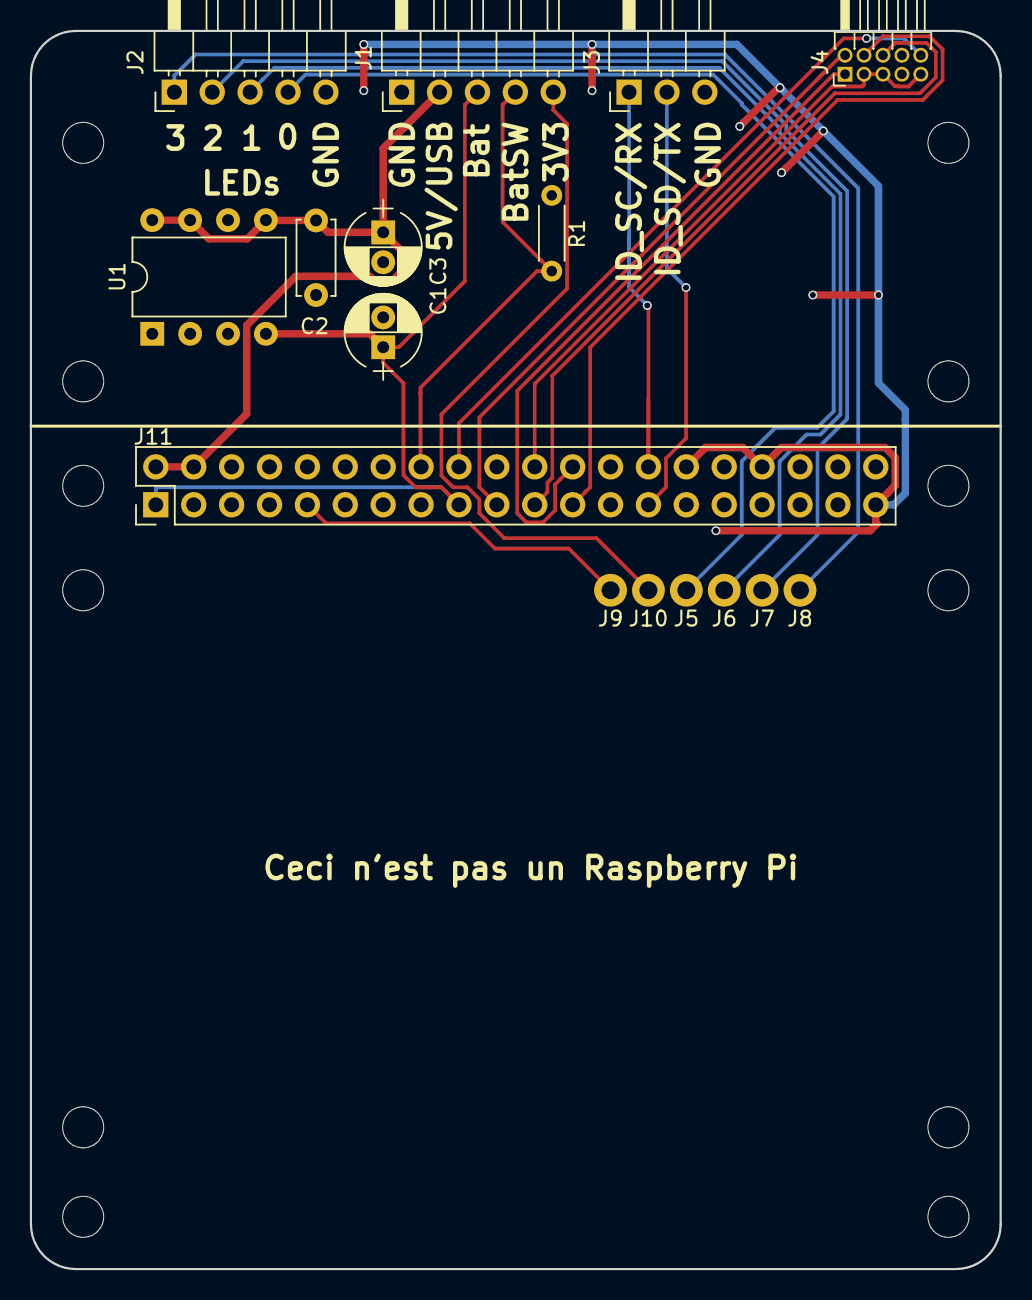
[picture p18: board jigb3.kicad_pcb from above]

Board: 2 copper layers, 65.0 x 83.0 mm, 16 parts (0 on the bottom side), 17 nets.

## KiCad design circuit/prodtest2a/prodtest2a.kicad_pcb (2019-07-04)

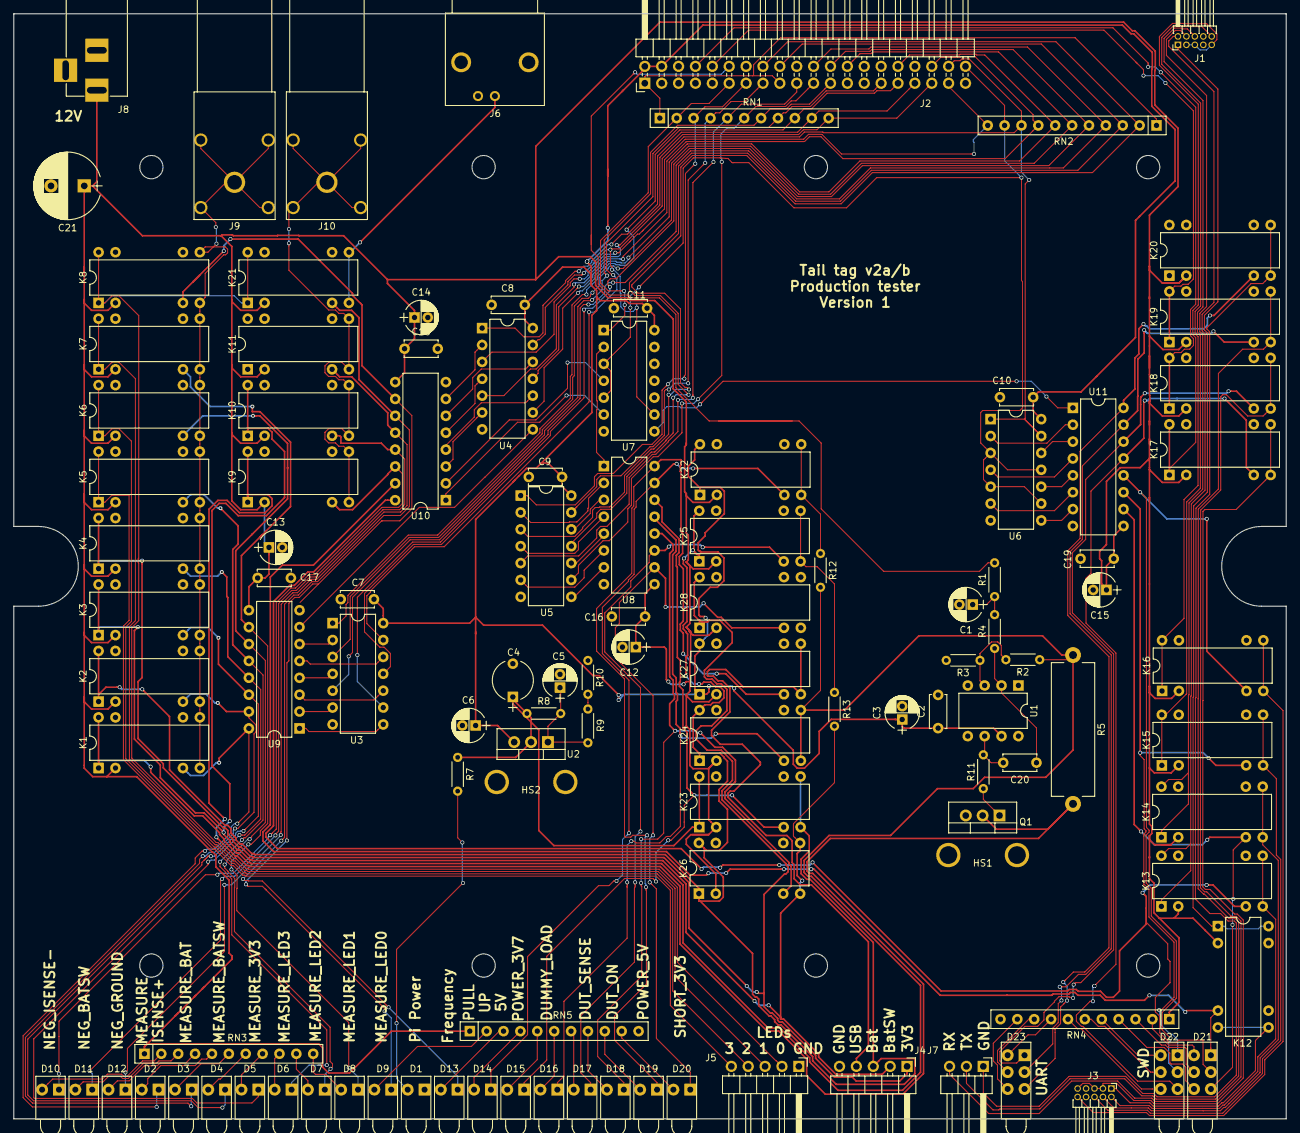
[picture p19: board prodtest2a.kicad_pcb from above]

Board: 2 copper layers, 191.5 x 166.3 mm, 113 parts (0 on the bottom side), 150 nets.

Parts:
C1, C3, C5, C6, C12, C13, C14, C15: 10u; CP_Radial_D5.0mm_P2.00mm
C2, C7, C8, C9, C10, C11, C16, C17, C18, C19, C20: 100n; C_Disc_D5.0mm_W2.5mm_P5.00mm
C4: 22u; CP_Radial_Tantal_D6.0mm_P5.00mm
C21: 1000u; CP_Radial_D10.0mm_P5.00mm
D1: GREEN; LED_D3.0mm_Horizontal_Housing_Z5.0mm
D2, D3, D4, D5, D6, D7, D8, D9, D10, D11, D12, D13, D14, D15, D16, D17, D18, D19, D20: RED; LED_D3.0mm_Horizontal_Housing_Z5.0mm
D21, D22, D23: Green; LED_D3.0mm_Horizontal_Housing_Triple
HS1, HS2: Heatsink; Heatsink_Aavid_581002B02500G
J1, J3: Conn_02x05_Odd_Even; Pin_Header_Angled_2x05_Pitch1.27mm
J2: Conn_02x20_Odd_Even; Pin_Header_Angled_2x20_Pitch2.54mm
J4, J5: Conn_01x05; Pin_Header_Angled_1x05_Pitch2.54mm
J6: Conn_Coaxial; BNC_Elbow_Socket_TE_1-1337543-0
J7: Conn_01x03; Pin_Header_Angled_1x03_Pitch2.54mm
J8: Barrel_Jack; BARREL_JACK
J9: Banana Red; Staubli_4mm_Angled_Socket
J10: Banana Black; Staubli_4mm_Angled_Socket
K1, K2, K3, K4, K5, K6, K7, K8, K9, K10, K11, K12, K13, K14, K15, K16, K17, K18, K19, K20, K21, K22, K23, K24, K25, K26, K27, K28: HE721A; DIP-14_8_W7.62mm
Q1: IPP034N03L; TO-220-3_Vertical
R1: 4k7; R_Axial_DIN0204_L3.6mm_D1.6mm_P5.08mm_Horizontal
R2, R3: 100k; R_Axial_DIN0204_L3.6mm_D1.6mm_P5.08mm_Horizontal
R4, R13: 10k; R_Axial_DIN0204_L3.6mm_D1.6mm_P5.08mm_Horizontal
R5: 0R2; R_Axial_Power_L20.0mm_W6.4mm_P22.40mm
R7, R8, R9, R10: 100; R_Axial_DIN0204_L3.6mm_D1.6mm_P5.08mm_Horizontal
R11, R12: 1k; R_Axial_DIN0204_L3.6mm_D1.6mm_P5.08mm_Horizontal
RN1, RN2: 10k; R_Array_SIP11
RN3, RN4, RN5: 1k; R_Array_SIP11
U1: MCP601-xP; DIP-8_W7.62mm
U2: LM1084-ADJ; TO-220-3_Vertical
U3, U4, U5, U6, U7: 74HCT04; DIP-14_W7.62mm
U8, U9, U10, U11: ULN2003A; DIP-16_W7.62mm

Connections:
3V3: J4.1, K4.1, K4.14, K28.1, K28.14
3V7: C4.1, K23.1, K23.14, R7.1, R8.1, U2.2
+5V: C2.1, C3.1, C6.1, C7.1, C8.1, C9.1, C10.1, C11.1, J2.2, J2.4, K22.1, K22.14, K27.1, K27.14, U1.7, U2.3, U3.14, U4.14, U5.14, U6.14, U7.14
+12V: C12.1, C13.1, C14.1, C15.1, C16.1, C17.1, C18.1, C19.1, C21.1, J8.1, K1.2, K2.2, K3.2, K4.2, K5.2, K6.2, K7.2, K8.2, K9.2, K10.2, K11.2, K12.2, K13.2, K14.2, K15.2, K16.2, K17.2, K18.2, K19.2, K20.2, K21.2, K22.2, K23.2, K24.2, K25.2, K26.2, K27.2, K28.2, RN3.1, RN4.1, RN5.1, U8.9, U9.9, U10.9, U11.9
BATSIM: K1.1, K1.14, K24.7, K24.8, R2.1, R5.1, R12.2
Bat: J4.3, K2.1, K2.14, K23.7, K23.8, K24.1, K24.14, K25.1, K25.14, K26.1, K26.14
BatSW: J4.2, K3.1, K3.14, K10.1, K10.14, K26.7, K26.8, R13.2
C_DUMMY_LOAD: D16.1, K24.6, U8.13
C_DUT_ON: D18.1, K26.6, U8.12
C_DUT_SENSE: D17.1, K25.6, U8.11
C_FREQUENCY: D13.1, K21.6, U10.11
C_MEASURE_3V3: D5.1, K4.6, U9.13
C_MEASURE_BAT: D3.1, K2.6, U9.15
C_MEASURE_BATSW: D4.1, K3.6, U9.14
C_MEASURE_ISENSE+: D2.1, K1.6, U9.16
C_MEASURE_LED0: D9.1, K8.6, U10.10
C_MEASURE_LED1: D8.1, K7.6, U9.10
C_MEASURE_LED2: D7.1, K6.6, U9.11
C_MEASURE_LED3: D6.1, K5.6, U9.12
C_NEG_BATSW: D11.1, K10.6, U10.13
C_NEG_GROUND: D12.1, K11.6, U10.12
C_NEG_ISENSE-: D10.1, K9.6, U10.14
C_POWER_3V7: D15.1, K23.6, U8.14
C_POWER_5V: D19.1, K27.6, U8.16
C_PULLUP_5V: D14.1, K22.6, U8.15
C_SHORT_3V3: D20.1, K28.6, U8.10
C_SWCLK: D21.3, K14.6, U11.10
C_SWDIO: D21.2, K13.6, U10.16
C_SWD_GND: D22.3, K17.6, U11.13
C_SWD_RESET: D22.2, K16.6, U11.12
C_SWD_VCC: D21.1, K12.6, U10.15
C_SWO: D22.1, K15.6, U11.11
C_UART_GND: D23.3, K20.6, U11.16
C_UART_RX: D23.1, K18.6, U11.14
C_UART_TX: D23.2, K19.6, U11.15
FREQUENCY: J6.1, K21.7, K21.8
GND: C1.2, C2.2, C3.2, C4.2, C5.2, C6.2, C7.2, C8.2, C9.2, C10.2, C11.2, C12.2, C13.2, C14.2, C15.2, C16.2, C17.2, C18.2, C19.2, C21.2, D1.1, J2.6, J2.9, J2.14, J2.20, J2.25, J2.30, J2.34, J2.39, J4.5, J6.2, J8.2, J8.3, K11.1, K11.14, K20.1, K20.14, K28.7, K28.8, Q1.3, R3.2, R10.2, U1.4, U3.7, U4.7, U5.7, U6.7, U7.7, U7.11, U7.13, U8.8, U9.8, U10.8, U11.8
ISENSE-: K9.1, K9.14, Q1.2, R5.2
LED0: J5.2, K8.1, K8.14, K21.1, K21.14
LED1: J5.3, K7.1, K7.14
LED2: J5.4, K6.1, K6.14
LED3: J5.5, K5.1, K5.14
METER+: J9.1, K1.7, K1.8, K2.7, K2.8, K3.7, K3.8, K4.7, K4.8, K5.7, K5.8, K6.7, K6.8, K7.7, K7.8, K8.7, K8.8
METER-: J10.1, K9.7, K9.8, K10.7, K10.8, K11.7, K11.8
unnamed: C1.1, R1.1, R4.2
unnamed: C5.1, R8.2, R9.1, U2.1
unnamed: C20.1, R4.1, U1.2
unnamed: C20.2, R11.2, U1.6
unnamed: D1.2, R7.2
unnamed: D2.2, RN3.5
unnamed: D3.2, RN3.6
unnamed: D4.2, RN3.7
unnamed: D5.2, RN3.8
unnamed: D6.2, RN3.9
unnamed: D7.2, RN3.10
unnamed: D8.2, RN3.11
unnamed: D9.2, RN5.2
unnamed: D10.2, RN3.2
unnamed: D11.2, RN3.3
unnamed: D12.2, RN3.4
unnamed: D13.2, RN5.3
unnamed: D14.2, RN5.4
unnamed: D15.2, RN5.5
unnamed: D16.2, RN5.6
unnamed: D17.2, RN5.7
unnamed: D18.2, RN5.8
unnamed: D19.2, RN5.9
unnamed: D20.2, RN5.10
unnamed: D21.4, RN4.4
unnamed: D21.5, RN4.3
unnamed: D21.6, RN4.2
unnamed: D22.4, RN4.7
unnamed: D22.5, RN4.6
unnamed: D22.6, RN4.5
unnamed: D23.4, RN4.10
unnamed: D23.5, RN4.9
unnamed: D23.6, RN4.8
unnamed: J2.1, J2.17, RN1.1, RN2.1
unnamed: K22.7, K22.8, R12.1
unnamed: K25.7, K25.8, R13.1
unnamed: Q1.1, R11.1
unnamed: R2.2, R3.1, U1.3
unnamed: R9.2, R10.1
unnamed: U3.2, U9.6
unnamed: U3.4, U9.4
unnamed: U3.6, U9.2
unnamed: U3.8, U9.1
unnamed: U3.10, U9.3
unnamed: U3.12, U9.5
unnamed: U4.8, U9.7
unnamed: U5.2, U8.2
unnamed: U5.4, U8.4
unnamed: U5.6, U8.6
unnamed: U5.8, U8.7
unnamed: U5.10, U8.5
unnamed: U5.12, U8.3
unnamed: U7.2, U8.1
unnamed: U7.6, U10.1
unnamed: U7.4, U10.2
unnamed: U4.6, U10.3
unnamed: U4.10, U10.4
unnamed: U4.4, U10.5
unnamed: U4.12, U10.6
unnamed: U4.2, U10.7
unnamed: U7.8, U11.1
unnamed: U6.2, U11.2
unnamed: U6.12, U11.3
unnamed: U6.4, U11.4
unnamed: U6.10, U11.5
unnamed: U6.6, U11.6
unnamed: U6.8, U11.7
PI_DUMMY_LOAD: J2.16, RN2.2, U5.3
PI_DUT_ON: J2.18, RN2.3, U5.11
PI_DUT_SENSE: J2.19, RN1.5, U5.5
PI_JTAG: J2.40, RN2.10, U6.3, U6.5, U6.9, U6.11, U7.3, U7.5
PI_MEASURE_3V3: J2.26, RN2.6, U3.3
PI_MEASURE_BAT: J2.23, RN1.7, U3.5
PI_MEASURE_BATSW: J2.24, RN2.5, U3.11
PI_MEASURE_ISENSE+: J2.22, RN2.4, U3.9
PI_MEASURE_LED0: J2.33, RN1.10, U4.1
PI_MEASURE_LED1: J2.32, RN2.7, U4.9
PI_MEASURE_LED2: J2.31, RN1.9, U3.1
PI_MEASURE_LED3: J2.29, RN1.8, U3.13
PI_NEG_BATSW: J2.36, RN2.8, U4.11
PI_NEG_GROUND: J2.37, RN2.11, U4.3
PI_NEG_ISENSE-: J2.35, RN1.11, U4.5
PI_POWER_3V7: J2.15, RN1.4, U5.13
PI_POWER_5V: J2.11, RN1.2, U7.1
PI_PULLUP_5V: J2.13, RN1.3, U5.1
PI_RXD: J2.10, K19.1, K19.14
PI_SHORT_3V3: J2.21, RN1.6, U5.9
PI_TXD: J2.8, K18.1, K18.14
PI_UART: J2.38, RN2.9, U4.13, U6.1, U6.13, U7.9
PWM_IN: J2.12, R1.2
SWCLK_IN: J1.4, K14.1, K14.14
SWCLK_OUT: J3.4, K14.7, K14.8
SWDIO_IN: J1.2, K13.1, K13.14
SWDIO_OUT: J3.2, K13.7, K13.8
SWD_GND_IN: J1.3, J1.5, J1.9, K17.1, K17.14
SWD_GND_OUT: J3.3, J3.5, J3.9, K17.7, K17.8
SWD_RESET_IN: J1.10, K16.1, K16.14
SWD_RESET_OUT: J3.10, K16.7, K16.8
SWD_VCC_IN: J1.1, K12.1, K12.14
SWD_VCC_OUT: J3.1, K12.7, K12.8
SWO_IN: J1.6, K15.1, K15.14
SWO_OUT: J3.6, K15.7, K15.8
UART_GND: J7.1, K20.7, K20.8
UART_RX: J7.3, K18.7, K18.8
UART_TX: J7.2, K19.7, K19.8
USB: J4.4, K27.7, K27.8

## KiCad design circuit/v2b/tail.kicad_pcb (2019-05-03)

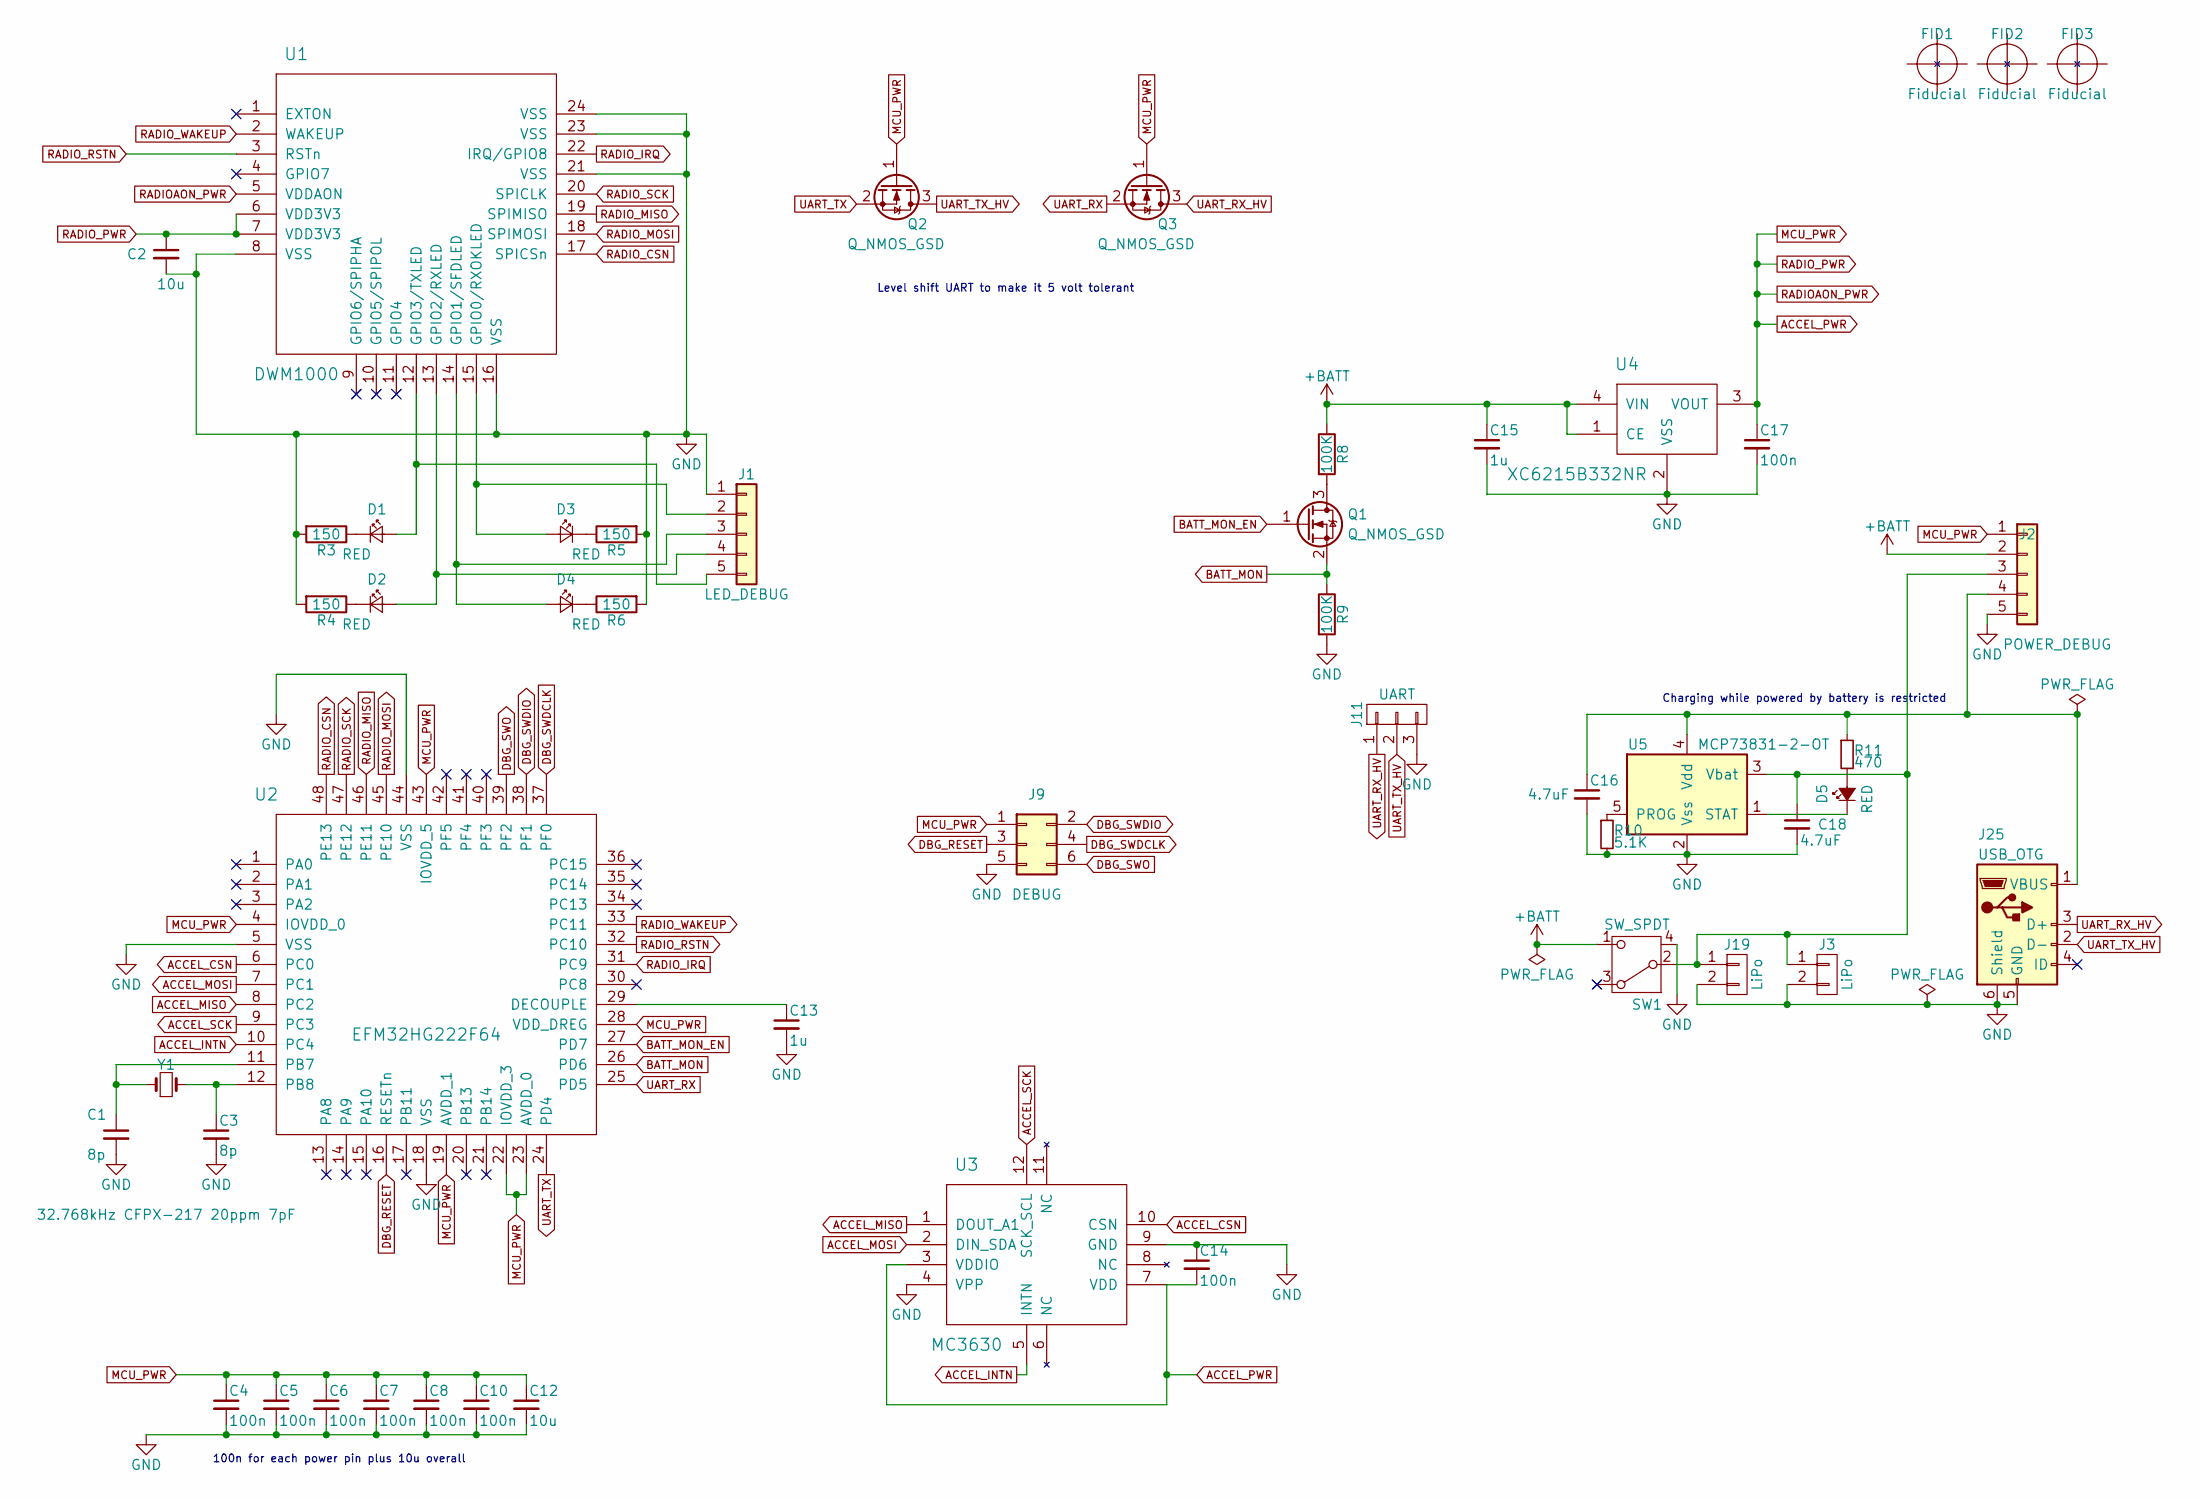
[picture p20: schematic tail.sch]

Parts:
C1, C3: 8p; C_0603; MPN MC0603N8R0D500CT
C2, C12: 10u; C_0603; MPN ZRB18AR61E106ME01L
C4, C5, C6, C7, C8, C10, C14, C17: 100n; C_0603; MPN MC0603B104K500CT
C13, C15: 1u; C_0603; MPN MC0603B105K160CT
C16, C18: 4.7uF; C_0603; MPN GRM188R60J475ME19D
D1, D2, D3, D4, D5: RED; LED_0603; MPN KP-1608SURCK
FID1, FID2, FID3: Fiducial; Fiducial_1mm_Dia_2.54mm_Outer_CopperTop
J1: LED_DEBUG; LED_DEBUG_Pads
J2: POWER_DEBUG; LED_DEBUG_Pads
J3: LiPo; Battery_SMD
J9: DEBUG; Debug_Pads
J11: UART; UART_Pads
J19: LiPo; JST_SH_SM02B-SRSS-TB_02x1.00mm_Angled; MPN SM02B-SRSS-TB (LF)(SN)
J25: USB_OTG; USB_Micro-B_SMD; MPN 47346-0001
Q1, Q2, Q3: Q_NMOS_GSD; SOT-323_SC-70; MPN NX3020NAKW
R3, R4, R5, R6: 150; R_0603; MPN MCWR06X1500FTL
R8, R9: 100K; R_0603; MPN MCWR06X1003FTL
R10: 5.1K; R_0603; MPN MCWR06X5101FTL
R11: 470; R_0603; MPN MCWR06X4700FTL
SW1: SW_SPDT; SWITCH_SSSS811101; MPN SSSS811101
U1: DWM1000; MPN DWM1000
U2: EFM32HG222F64; EFM32_TQFP48; MPN EFM32HG222F64G-B-QFP48
U3: MC3630; VLGA-12; MPN MC3630
U4: XC6215B332NR; SSOT-24; MPN XC6215B332NR
U5: MCP73831-2-OT; SOT-23-5; MPN MCP73831T-2ACI/OT
Y1: 32.768kHz CFPX-217 20ppm 7pF; Crystal_SMD_3215-2pin_3.2x1.5mm; MPN LFXTAL009709

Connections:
+BATT: C15.1, J2.2, R8.1, SW1.1 (B), U4.1 (CE), U4.4 (VIN)
ACCEL_CSN: U2.6 (PC0), U3.10 (CSN)
ACCEL_INTN: U2.10 (PC4), U3.5 (INTN)
ACCEL_MISO: U2.8 (PC2), U3.1 (DOUT_A1)
ACCEL_MOSI: U2.7 (PC1), U3.2 (DIN_SDA)
ACCEL_PWR: C2.1, C4.1, C5.1, C6.1, C7.1, C8.1, C10.1, C12.1, C14.2, C17.1, J2.1, J9.1, Q2.1 (G), Q3.1 (G), U1.5 (VDDAON), U1.6 (VDD3V3), U1.7 (VDD3V3), U2.4 (IOVDD_0), U2.19 (AVDD_1), U2.22 (IOVDD_3), U2.23 (AVDD_0), U2.28 (VDD_DREG), U2.43 (IOVDD_5), U3.3 (VDDIO), U3.7 (VDD), U4.3 (VOUT)
ACCEL_SCK: U2.9 (PC3), U3.12 (SCK_SCL)
BATT_MON: Q1.2 (S), R9.1, U2.26 (PD6)
BATT_MON_EN: Q1.1 (G), U2.27 (PD7)
DBG_RESET: J9.3, U2.16 (RESETn)
DBG_SWDCLK: J9.4, U2.37 (PF0)
DBG_SWDIO: J9.2, U2.38 (PF1)
DBG_SWO: J9.6, U2.39 (PF2)
GND: C1.2, C2.2, C3.2, C4.2, C5.2, C6.2, C7.2, C8.2, C10.2, C12.2, C13.2, C14.1, C15.2, C16.2, C17.2, C18.2, J1.1, J2.5, J3.2, J9.5, J11.3, J19.2, J25.5 (GND), J25.6 (Shield), R3.2, R4.2, R5.2, R6.2, R9.2, R10.2, SW1.4 (Body), U1.8 (VSS), U1.16 (VSS), U1.21 (VSS), U1.23 (VSS), U1.24 (VSS), U2.5 (VSS), U2.18 (VSS), U2.44 (VSS), U3.4 (VPP), U3.9 (GND), U4.2 (VSS), U5.2 (Vss)
unnamed: C1.1, U2.11 (PB7), Y1.1
unnamed: C3.1, U2.12 (PB8), Y1.2
unnamed: C13.1, U2.29 (DECOUPLE)
unnamed: C16.1, J2.4, J25.1 (VBUS), R11.1, U5.4 (Vdd)
unnamed: C18.1, J2.3, J3.1, J19.1, SW1.2 (C), U5.3 (Vbat)
unnamed: D1.1 (K), R3.1
unnamed: D1.2 (A), J1.5, U1.12 (GPIO3/TXLED)
unnamed: D2.1 (K), R4.1
unnamed: D2.2 (A), J1.4, U1.13 (GPIO2/RXLED)
unnamed: D3.1 (K), R5.1
unnamed: D3.2 (A), J1.2, U1.15 (GPIO0/RXOKLED)
unnamed: D4.1 (K), R6.1
unnamed: D4.2 (A), J1.3, U1.14 (GPIO1/SFDLED)
unnamed: D5.1 (K), U5.1 (STAT)
unnamed: D5.2 (A), R11.2
unnamed: Q1.3 (D), R8.2
unnamed: R10.1, U5.5 (PROG)
RADIO_CSN: U1.17 (SPICSn), U2.48 (PE13)
RADIO_IRQ: U1.22 (IRQ/GPIO8), U2.31 (PC9)
RADIO_MISO: U1.19 (SPIMISO), U2.46 (PE11)
RADIO_MOSI: U1.18 (SPIMOSI), U2.45 (PE10)
RADIO_RSTN: U1.3 (RSTn), U2.32 (PC10)
RADIO_SCK: U1.20 (SPICLK), U2.47 (PE12)
RADIO_WAKEUP: U1.2 (WAKEUP), U2.33 (PC11)
UART_RX: Q3.2 (S), U2.25 (PD5)
UART_RX_HV: J11.1, J25.3 (D+), Q3.3 (D)
UART_TX: Q2.2 (S), U2.24 (PD4)
UART_TX_HV: J11.2, J25.2 (D-), Q2.3 (D)

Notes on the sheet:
Charging while powered by battery is restricted
100n for each power pin plus 10u overall
Level shift UART to make it 5 volt tolerant

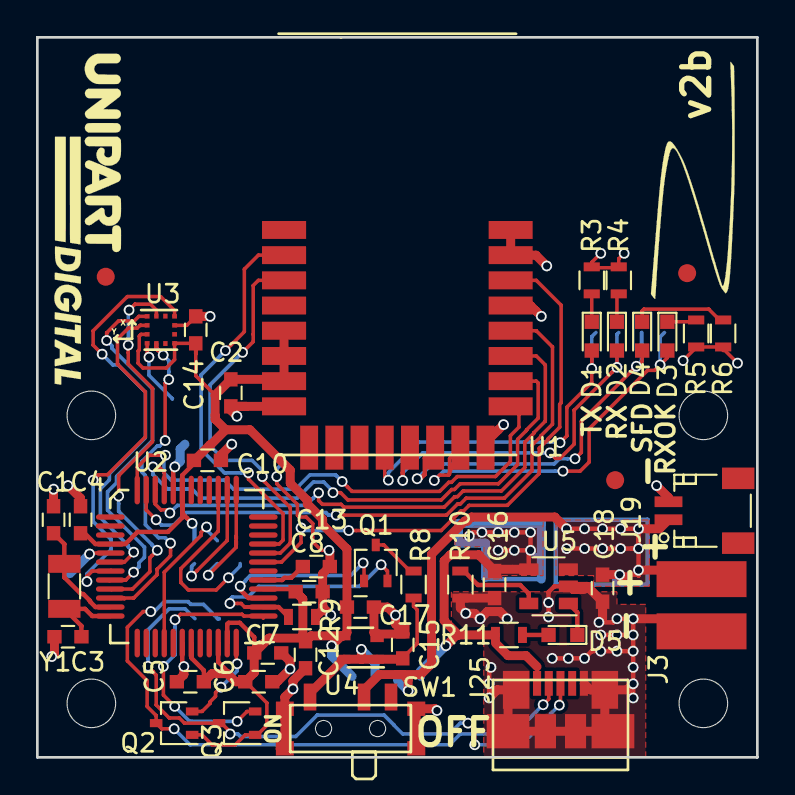
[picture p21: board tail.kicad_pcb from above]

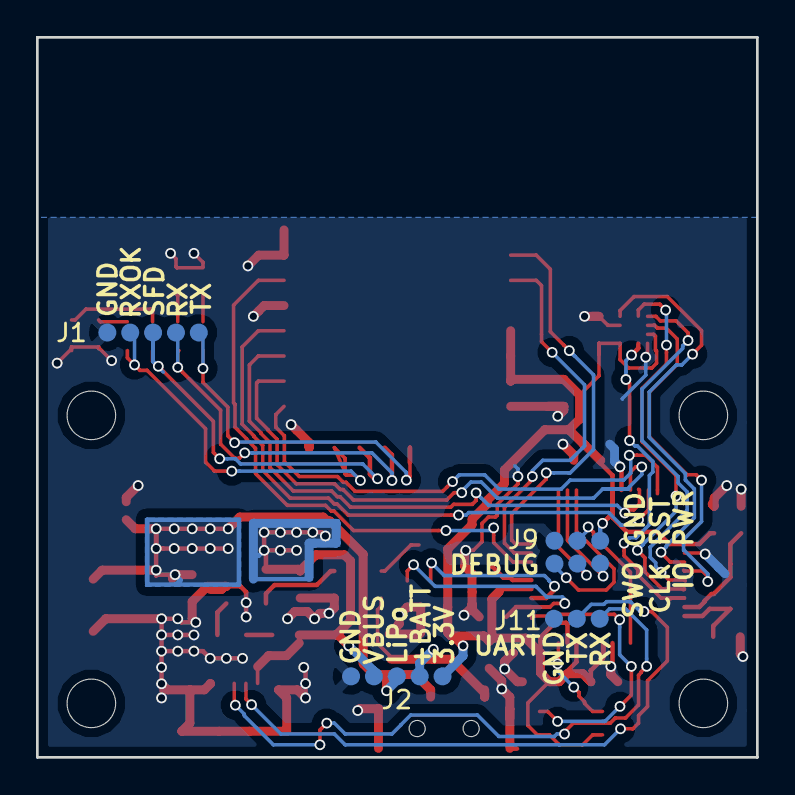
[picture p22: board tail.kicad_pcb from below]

Board: 2 copper layers, 40.0 x 40.0 mm, 51 parts (4 on the bottom side), 42 nets.

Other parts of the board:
G1: LOGO; Unipart_Digital_logo
G2: LOGO; Tail_logo

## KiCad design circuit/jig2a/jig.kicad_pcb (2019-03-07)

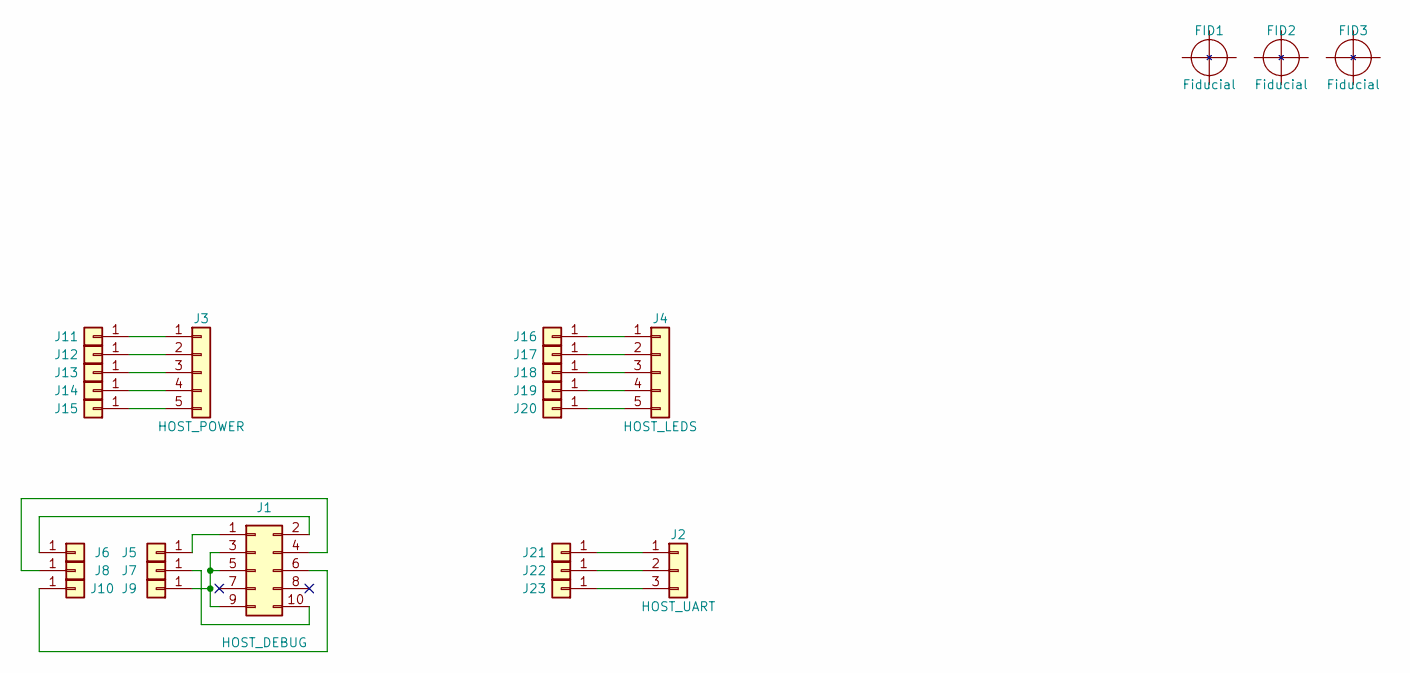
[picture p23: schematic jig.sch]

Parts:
FID1, FID2, FID3: Fiducial; Fiducial_1mm_Dia_2.54mm_Outer_CopperTop
J1: HOST_DEBUG; Pin_Header_Straight_2x05_Pitch1.27mm_SMD; MPN FTSH-105-01-L-DV
J2: HOST_UART; Pin_Header_Straight_1x03_Pitch2.54mm; MPN 2211-03G
J3: HOST_POWER; Pin_Header_Straight_1x05_Pitch2.54mm; MPN 2211S-05G
J4: HOST_LEDS; Pin_Header_Straight_1x05_Pitch2.54mm; MPN 2211S-05G
J5, J6, J7, J8, J9, J10, J11, J12, J13, J14, J15, J16, J17, J18, J19, J20, J21, J22, J23: S13; Harwin-Sleeve-S13-1.27mm; MPN S13-503

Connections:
unnamed: J1.1, J5.1
unnamed: J1.2, J6.1
unnamed: J1.3, J1.5, J1.9, J9.1
unnamed: J1.4, J8.1
unnamed: J1.6, J10.1
unnamed: J1.10, J7.1
unnamed: J2.1, J21.1
unnamed: J2.2, J22.1
unnamed: J2.3, J23.1
unnamed: J3.1, J11.1
unnamed: J3.2, J12.1
unnamed: J3.3, J13.1
unnamed: J3.4, J14.1
unnamed: J3.5, J15.1
unnamed: J4.1, J16.1
unnamed: J4.2, J17.1
unnamed: J4.3, J18.1
unnamed: J4.4, J19.1
unnamed: J4.5, J20.1

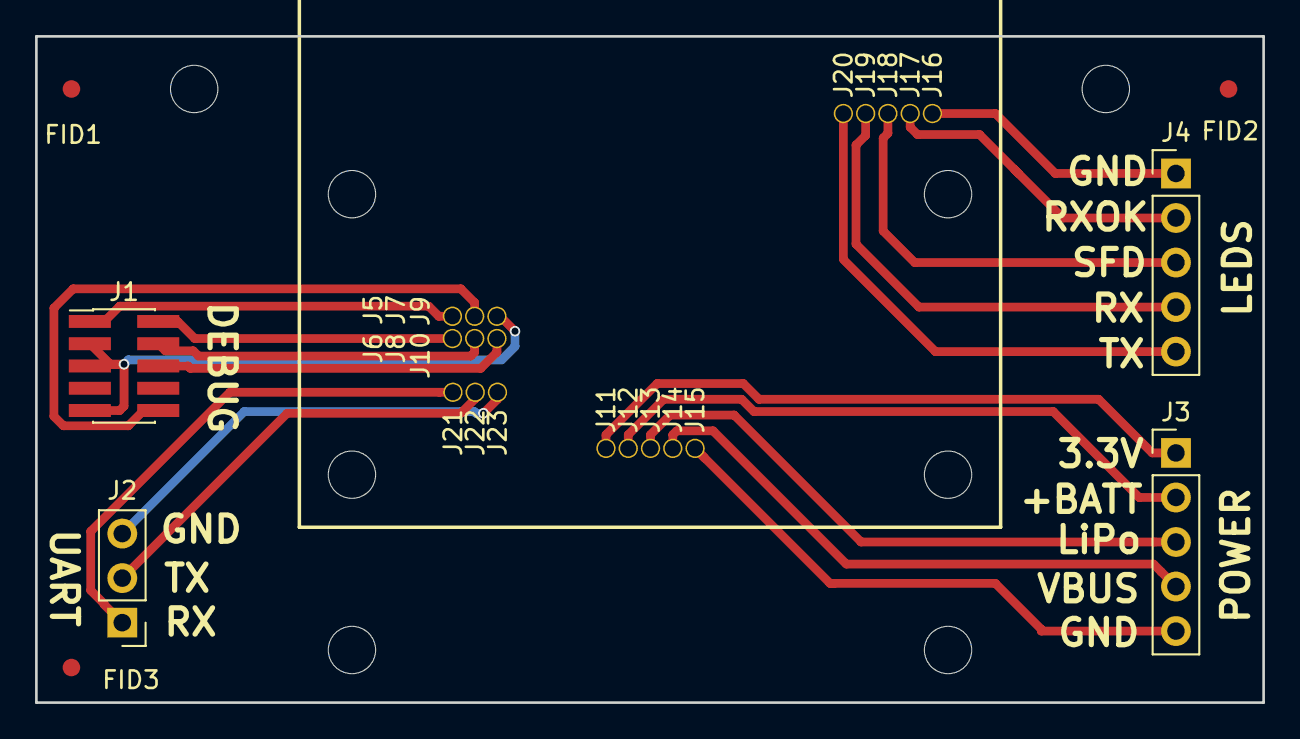
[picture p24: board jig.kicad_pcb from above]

Board: 2 copper layers, 70.0 x 38.0 mm, 26 parts (0 on the bottom side), 19 nets.

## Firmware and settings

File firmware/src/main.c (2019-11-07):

#include "em_device.h"
#include "em_chip.h"
#include "em_cmu.h"
#include "em_gpio.h"
#include "em_leuart.h"
#include "em_emu.h"
#include "em_rmu.h"

#include "common.h"
#include "radio.h"
#include "radio_spi.h"
#include "radio_reg.h"
#include "accel.h"
#include "uart.h"
#include "cli.h"
#include "time.h"
#include "config.h"
#include "proto.h"
#include "timer.h"
#include "event.h"
#include "entropy.h"
#include "crypto.h"

#define CLOCK_DEBUG 0

/* XXX no longer used */
#define ANTENNA_DELAY_TX 16434
#define ANTENNA_DELAY_RX 16434

radio_config_t radio_config = {
		/* chan */        5,
		/* prf_high */    false,
		/* tx_plen */     RADIO_PLEN_128,
		/* rx_pac */      RADIO_PAC_8,
		/* tx_pcode */    4,
		/* rx_pcode */    4,
		/* ns_sfd */      false,
		/* data_rate */   RADIO_RATE_6M8,
		/* long_frames */ false,
		/* sfd_timeout */ 0
};


uint8_t xtal_trim;

extern void *__StackTop;
extern void *__StackLimit;
extern void *__HeapLimit;
extern void *__HeapBase;

int main(void)
{
  /* Chip errata */
  CHIP_Init();
  /* Enable oscillator here so that we can do other initialisation while
   * it is stabilising. uart_init() will block until the oscillator is
   * stabilised.
   */
  CMU_OscillatorEnable(cmuOsc_LFXO, true, false);

  memset(&__HeapBase, 0x5A, &__StackTop - &__HeapBase - 0x100);

  CMU_HFRCOBandSet(cmuHFRCOBand_21MHz);

  CMU_ClockEnable(cmuClock_GPIO, true);

  GPIO_PinModeSet(gpioPortA, 0, gpioModePushPull, 1);

#if CLOCK_DEBUG
  /* Select HFRCO as source for CMU_CLK0 pin */
    CMU->CTRL =(CMU->CTRL &~_CMU_CTRL_CLKOUTSEL0_MASK)| CMU_CTRL_CLKOUTSEL0_HFRCO;
//    CMU->CTRL =(CMU->CTRL &~_CMU_CTRL_CLKOUTSEL1_MASK)| CMU_CTRL_CLKOUTSEL1_HFCLK;
//    CMU->CTRL =(CMU->CTRL &~_CMU_CTRL_CLKOUTSEL0_MASK)| CMU_CTRL_CLKOUTSEL0_HFRCO;
//    CMU->CTRL =(CMU->CTRL &~_CMU_CTRL_CLKOUTSEL1_MASK)| CMU_CTRL_CLKOUTSEL1_LFRCO;
    CMU->CTRL =(CMU->CTRL &~_CMU_CTRL_CLKOUTSEL1_MASK)| CMU_CTRL_CLKOUTSEL1_LFXO;
  CMU->ROUTE = CMU_ROUTE_LOCATION_LOC0 | CMU_ROUTE_CLKOUT0PEN | CMU_ROUTE_CLKOUT1PEN;
  /* Configure PA12 as push-pull output */
  GPIO_PinModeSet(gpioPortA, 2, gpioModePushPull ,0);
  GPIO_PinModeSet(gpioPortA, 1, gpioModePushPull ,0);
#endif
  GPIO_PinModeSet(gpioPortA, 1, gpioModePushPull ,0);

  /* Battery monitor disable - saves a couple of microamps */
  GPIO_PinModeSet(gpioPortD, 7, gpioModePushPull, 0);

  delay(100);
  event_clear();
  time_init();
  config_init();
  radio_init(true);
  bool accel_present = accel_init();

  xtal_trim = 0x10; // Default value in radio driver
  if (config_get(config_key_xtal_trim, &xtal_trim, 1))
	  radio_xtal_trim(xtal_trim);

  /* Defer uart_init() until the latest possible time, because it will wait
   * for the LFXO to be stable.
   */
  uart_init(config_get8(config_key_uart_drive));

  uint32_t reset_cause = RMU_ResetCauseGet();
  RMU_ResetCauseClear();


#define RMU_RSTCAUSE_PORST_XMASK         0x00000000UL
#define RMU_RSTCAUSE_BODUNREGRST_XMASK   0x00000081UL
#define RMU_RSTCAUSE_BODREGRST_XMASK     0x00000091UL
#define RMU_RSTCAUSE_EXTRST_XMASK        0x00000001UL
#define RMU_RSTCAUSE_WDOGRST_XMASK       0x00000003UL
#define RMU_RSTCAUSE_LOCKUPRST_XMASK     0x0000EFDFUL
#define RMU_RSTCAUSE_SYSREQRST_XMASK     0x0000EF9FUL
#define RMU_RSTCAUSE_EM4RST_XMASK        0x00000719UL
#define RMU_RSTCAUSE_EM4WURST_XMASK      0x00000619UL
#define RMU_RSTCAUSE_BODAVDD0_XMASK      0x0000041FUL
#define RMU_RSTCAUSE_BODAVDD1_XMASK      0x0000021FUL

  if (reset_cause & RMU_RSTCAUSE_PORST)
	  write_string("Power on reset\r\n");
  if (reset_cause & RMU_RSTCAUSE_BODUNREGRST)
	  write_string("Brownout in unregulated domain\r\n");
  if (reset_cause & RMU_RSTCAUSE_BODREGRST)
	  write_string("Brownout in regulated domain\r\n");
  if (reset_cause & RMU_RSTCAUSE_EXTRST)
	  write_string("External reset\r\n");
  if (reset_cause & RMU_RSTCAUSE_WDOGRST)
	  write_string("Watchdog reset\r\n");
  if (reset_cause & RMU_RSTCAUSE_LOCKUPRST)
	  write_string("Lockup reset\r\n");
  if (reset_cause & RMU_RSTCAUSE_SYSREQRST)
	  write_string("System requested reset\r\n");
  if (reset_cause & RMU_RSTCAUSE_EM4RST)
	  write_string("Woke up from EM4\r\n");
  if (reset_cause & RMU_RSTCAUSE_EM4WURST)
	  write_string("Woken from EM4 by pin\r\n");
  if (reset_cause & RMU_RSTCAUSE_BODAVDD0)
	  write_string("Brownout in analogue domain 0\r\n");
  if (reset_cause & RMU_RSTCAUSE_BODAVDD1)
	  write_string("Brownout in analogue domain 1\r\n");

  if (accel_present)
      write_string("Accelerometer detected\r\n");
  else
	  write_string("No accelerometer detected\r\n");

  cli_init();

  uint8_t sniff_sensitivity = 2;
  uint8_t sniff_exponent = 0;
  uint8_t sniff_mode = 1;
  uint8_t sniff_count = 0;
  (void) config_get(config_key_accel_sensitivity, &sniff_sensitivity, 1);
  (void) config_get(config_key_accel_exponent, &sniff_exponent, 1);
  (void) config_get(config_key_accel_mode, &sniff_mode, 1);
  (void) config_get(config_key_accel_count, &sniff_count, 1);
  accel_enter_mode(ACCEL_STANDBY);
  accel_config_power_mode(ACCEL_ULP, ACCEL_ULP);
  accel_config_range_resolution(ACCEL_2G, ACCEL_6BITS);
  accel_config_rate(ACCEL_ULP_ODR_25);
  accel_config_threshold(sniff_sensitivity, sniff_sensitivity, sniff_sensitivity, sniff_exponent);
  if (sniff_count > 0)
      accel_config_detection_count(sniff_count-1, sniff_count-1, sniff_count-1, true);
  else
      accel_config_detection_count(0, 0, 0, false);
  accel_config_sniff_mode(false, sniff_mode);

  accel_enter_mode(ACCEL_SNIFF);

    radio_leds(true, config_get8(config_key_radio_leds));

    uint8_t byte;

    (void) config_get(config_key_chan, &radio_config.chan, sizeof(radio_config.chan));
    if (config_get(config_key_prf_high, &byte, 1) > 0)
    	radio_config.prf_high = byte?true:false;
    (void) config_get(config_key_tx_plen, &radio_config.tx_plen, sizeof(radio_config.tx_plen));
    (void) config_get(config_key_rx_pac, &radio_config.rx_pac, sizeof(radio_config.rx_pac));
    (void) config_get(config_key_tx_pcode, &radio_config.tx_pcode, sizeof(radio_config.tx_pcode));
    (void) config_get(config_key_rx_pcode, &radio_config.rx_pcode, sizeof(radio_config.rx_pcode));
    if (config_get(config_key_ns_sfd, &byte, 1) > 0)
    	radio_config.ns_sfd = byte?true:false;
    (void) config_get(config_key_data_rate, &radio_config.data_rate, sizeof(radio_config.data_rate));
    if (config_get(config_key_long_frames, &byte, 1) > 0)
    	radio_config.long_frames = byte?true:false;
    (void) config_get(config_key_sfd_timeout, (uint8_t *)&radio_config.sfd_timeout, sizeof(radio_config.sfd_timeout));


    radio_configure(&radio_config);
	radio_doublebuffer(true);

    radio_spi_speed(true);

    set_antenna_delay_tx(config_get16(config_key_antenna_delay_tx));
    set_antenna_delay_rx(config_get16(config_key_antenna_delay_rx));

    uint32_t word = 0;

    if (config_get(config_key_tx_power, (uint8_t *)&word, 4) > 0)
    	radio_settxpower(word);
    if (config_get(config_key_smart_tx_power, &byte, 1) > 0)
    	radio_smarttxpowercontrol(byte);

    word = 0;
    if (config_get(config_key_turnaround_delay, (uint8_t *)&word, 4) > 0)
        proto_turnaround_delay(word);

    word = 0;
    if (config_get(config_key_rxtimeout, (uint8_t *)&word, 4) > 0)
    	proto_rx_timeout(word);

    word = 0;
    if (config_get(config_key_rxdelay, (uint8_t *)&word, 4) > 0)
        proto_rx_delay(word);

    crypto_init();
    proto_init();

    while (1) {
    	time_event_poll();
        cli_poll();
        proto_poll();
        accel_poll();
        entropy_poll();
        if (!cli_prepare_sleep())
        	continue;
        if (!uart_prepare_sleep())
        	continue;
        if (!time_prepare_sleep())
        	continue;
        if (!timer_prepare_sleep())
        	continue;
        EMU_EnterEM2(true);
    }
}

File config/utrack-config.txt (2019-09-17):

config chan 5
config prf_high 1
config ns_sfd 0
config long_frames 0
config sfd_timeout 0
config smart_tx_power 0
config accel_exponent 0
config accel_mode 1
config accel_count 1
config accel_sensitivity 2
config tx_pcode 12
config rx_pcode 12
config turnaround_delay 0x88 0x13
config tx_plen 8
config rx_pac 3
config data_rate 1
config rxtimeout 0x86 0x09
config rxdelay 0x86 0x09
config antenna_delay_rx 0x20 0x40
config antenna_delay_tx 0x20 0x40
config tx_power 0xd1 0xd1 0xd1 0xd1
config tag_transition_time 10
config tag_max_anchors 8
config tag_min_responses 0
config tag_period_idle 0xa0 0x86 0x1
config tag_period 0xE8 0x03
config tag_jitter 200
config tag_jitter_idle 200

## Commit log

2017-10-26 [kernel] Create proof of concept 802.15.4 kernel driver for Tail board
    Create basic IEEE 802.15.4 kernel driver capable of sending and
    receiving packets via the Tail board's UART port.
    This driver is tested with wpan-ping (up to a packet size of around 16
    bytes, at which point the speed of the 9600 baud UART link starts
    inducing timeout failures). IPv6 via the kernel's lowpan driver is
    partially working, but with an incredibly high packet loss rate
    (possibly also induced by the UART speed limit).
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2017-11-06 [pitail] Add initial circuit sketch
    Add initial circuit sketch for the DWM1000 Raspberry Pi Hat. This
    sketch includes only the logical connections and required breakout
    points.
    [pitail.sch]
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2017-11-06 [pitail] Add part numbers for resistors and LEDs
    Choose resistor and LED part numbers from the PCB Train free
    components list.
    [pitail.sch]
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2018-01-12 Commit snapshot of tail firmware. Currently without Simplicity Studio/Eclipse project files as I'm not yet sure how to commit those in a safe way that doesn't depend on specific machines and pathname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
    Maybe this will be motivation to write some proper Makefiles.
    [accel.c, accel.h, accel_spi.c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]
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2018-01-22 [pitail] Add empty mechanical design
    Derived from https://github.com/xesscorp/RPi_Hat_Template:
    - deleted J2 connector (through-hole)
    - deleted smaller upper board edge
    - renamed J1 to J0
    - tidied up text
    [pitail.kicad_pcb]
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2018-01-23 [pitail] Use only the more accessible of the two 3V3 power lines
    Simplify PCB routing by using only one of the two 3V3 supply lines.
    We are using this to power only the EEPROM; the bulk of our power
    comes from the 5V lines.
    [pitail.sch]
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2018-01-24 [pitail] Correct part number for 22uF capacitor
    [pitail.sch]
2018-01-24 [pitail] Set fabrication parameters
    Set fabrication parameters for Elecrow as per instructions at
    http://www.360customs.de/en/2017/01/kicad-elecrow-pcb-service/
    [pitail.kicad_pcb]
2018-01-24 [pitail] Move silk screen text to avoid vias
    [pitail.kicad_pcb]
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2018-02-08 [dw1000] Perform soft reset during probe
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2018-02-14 [dw1000] Reset device on shutdown
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2018-02-14 [dw1000] Correct received frame length
2018-02-14 [dw1000] Include checksum within received packet
    The Linux IEEE 802.15.4 core currently calculates a faked receive
    checksum in ieee802154_rx() if the driver does not provide one. It
    will append this checksum to the buffer, potentially causing kernel
    panics with our driver since we allocate only enough space to hold the
    packet content.
    Include the actual received checksum within the packet as delivered to
    the IEEE 802.15.4 stack. Since we continue to advertise our ability
    to drop bad packets (via the IEEE802154_HW_RX_DROP_BAD_CKSUM flag),
    this avoids all unnecessary checksum recalculations, and prevents the
    kernel panics due to the assumption of extra space in ieee802154_rx().
    Signed-off-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
2018-02-16 [dw1000] Report transmit timestamps only when requested
    Reporting transmit timestamps incurs a non-trivial cost of cloning the
    skb and queueing a copy of the transmitted packet on the socket's
    error queue. Do this only for those packets where the sending socket
    has actually requested timestamping.
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2018-02-28 [dw1000] Do not reset receiver when an overrun occurs
    Experiments show that the receiver reset process is massively
    disruptive to both transmit and receive datapaths, and prone to a
    failure mode in which the RXENAB command is simply ignored, resulting
    in a completely dead receiver.
    In contrast, simply toggling HRBPT seems to work reliably. The only
    subtlety is that we need to treat an RXOVRR interrupt in the same way
    as an RXDFR interrupt, since RXDFR will not be asserted in the event
    of an overrun.
    Remove the complexity of the receiver reset mechanism, and simply
    discard any packets for which an overrun has occurred.
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2018-03-06 [pitail] Change voltage regulator to MCP1825S
    The Diodes Inc. AP1117E33G-13 regulator was unstable and produced an
    approximately 2kHz oscillation of +/- 0.5V on the 3.3V output. Switch
    for a Microchip MCP1825S-3302E/DB voltage regulator.
    Recommended-by: Richard Neill <richard.neill@unipart.com>
    [pitail.sch]
2018-03-06 [pitail] Add power LED
    Add power indicator LED to provide a lower bound on the voltage
    regulator output power consumption.
    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
    [pitail.sch]
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2018-03-12 [pitail] Mark power LED as to be removed in final design
    Mark power LED and accompanying resistor as to be removed in the final
    design, and renumber components accordingly.
    [pitail.kicad_pcb, pitail.sch]
2018-03-13 [pitail] Move publishable components to public GitHub repository
    Move kernel driver, Pi Tail PCB design, and EEPROM generator to
    https://github.com/mcb30/dw1000.git
    The public repository was created using git filter-branch to retain
    this repository's version history.
    [pitail.kicad_pcb, pitail.sch]
2018-03-26 [scripts] Add kernel driver and linuxptp test scripts
    Add the temporary test scripts used on the Pi Tail, for the record.
    These should be deleted when no longer relevant.
    The scripts assume the existence of:
    - dw1000 kernel driver tree at ~/kernel
    - linuxptp source tree at ~/linuxptp
    This assumption will be removed once we have cross-compilation set up
    and working.
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2018-07-08 Add basic sleep code to the driver, and cli commands to test it. Also, adjust the radio initialisation routine to attempt to bring the radio out of sleep prior to resetting it, as reset is not possib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
    [cli.c]
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2018-08-24 rtls: Add Rx Power level correction
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2018-10-02 tail: Sort out BOM and fix ERC
    [tail.sch]
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2018-10-02 tail: More detail for SSSS811101 slide switch
    This involves correcting the schematic and the symbol to match up the
    pin numbering with the datasheet, and to add a case/body connection.
    [tail.sch]
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2018-10-03 tail: Change UART connector to right angle
    ... and move things around to make it fit.
    [tail.kicad_pcb, tail.sch]
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2018-10-04 tail: correct Insert field for fabrication
    Also, .xml regeneration along the way.
    [tail.kicad_pcb]
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2018-10-09 case: add demo case for tail v2 tag
    The PDF and STL files are for convenience for people who don't have
    FreeCAD installed.
    The svg and dxf files were used to generate the logo on the lid.
    [case.fcstd, case.stl, tail-logo-simplified-scaled.dxf]
2018-10-24 firmware: full accelerometer support
    The accelerometer is now probed on v1 and v2 pins, and is now used in
    tagipv6 functionality to set a variable blink interval based on motion.
    Configuration parameters exist to set the sensitivity of the acceloremeter
    while in sniff mode, as well as to specify a time for which the tag will
    remain in active mode after the last detected motion.
    In its present form, the code will cause the tag to enter active mode
    approximately once every 1.52 days, when the timer wraps around. This
    should be fixed eventually.
    [accel.c, accel.h, accel_spi.c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]
2018-11-05 case: Move UART connector to match fabricated PCB
    This also involves creating a hole in the lid, and a number of edges
    and faces split/renumbered.
    [case.fcstd, case.stl]
2018-11-05 case: Add optional hole for debug connector
    Controlled by DebugVisible which must be 0 or 1.
    [case-lid.stl, case.fcstd]
2018-11-05 case: Add a bit of clearance to the debug connector
    Also, correct DebugDepth.
    [case-lid.stl, case.fcstd]
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2019-01-21 tag: v2a PCB with solder pads for battery
    This is a 40x40mm PCB with mounting holes and the battery soldered
    directly to the PCB. The USB connector and power switch are on the bottom
    to allow for the PCB to be vertically mounted in a case which is at least
    moderately protected from rain falling from above.
    [tail.kicad_pcb, tail.sch]
2019-01-21 tag: Add low profile battery connector
    Preserve solder pads in case we need to hand solder a battery after all
    [tail.kicad_pcb, tail.sch]
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2019-01-28 jig: Add CAD model for jig incorporating tag v2a and the jig PCB v2a.
    This also includes the manufacturer's CAD model for the toggle clamp,
    and uses the Fasteners workbench and the Exploded Assembly workbench,
    both of which must be installed via FreeCAD's plugin menu.
    The Exploded Assembly workbench will show an animation of the assembly
    or disassembly of this.
    [jig.fcstd]
2019-01-28 jig: Commit STL files for the jig body spacer for printing
    These are the result of exporting the body and the spacer separately.
    Print the body upside down so that the overhangs do not have holes
    in them.
    [jig-body.stl, jig-spacer.stl]
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2019-02-14 prodtest2a: Production test equipment schematic
    This is to be built by hand as a mix of stripboard for the electronics
    and plain wiring for the relays and other connections. Designed to work
    with the jig for v2a.
    [prodtest2a.kicad_pcb, prodtest2a.sch]
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2019-02-14 case: Add v2a prototype case.
    This is designed for a single M2 countersunk bolt with a hex nut. A 9mm
    bolt will be slightly too long and will stick out, an 8mm bolt will probably
    work but won't engage with the entire thickness of the nut.
    There's an absence of support over the battery area. This may need improving.
    Also, the single screw design may be insufficient, depending on the
    flexibility of the material.
    This is mostly designed to be injection mouldable, although there are still
    a few areas where corners are potentially too sharp for that process. Once
    we're happy with the design, a review by an injection moulding expert would
    be a very good idea.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
    [case.FCStd]
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2019-02-20 tester: Add tf390 class and periodic polling for the device
    There's framework here for the other devices to be polled
    too, and for the test, when run, to acquire a lock on
    the devices in order to run without interference from
    the poller
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2019-03-07 jig: Correct positioning of power debug pins
    [jig-B.Cu.gbr, jig-B.Mask.gbr, jig-B.SilkS.gbr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]
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2019-03-14 firmware: Measure battery voltage with ADC and report in blink packets
    Also, check in file that was missed off a previous commit.
    Note that at present we're just using a linear estimator between 3.6
    volts and 4.1 volts for state of charge. This isn't particularly
    accurate, but gets us going until we revisit this to come up with
    a more accurate state of charge estimator.
    Also, the battery voltage is filtered with an exponential weighted
    average filter to keep it stable. The tag needs to wake up about 16
    times after a significant change to the battery voltage (such as
    fast charging while the tag is idle) to start reporting an accurate
    state.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
    [adc.c, battery.c]
2019-03-22 firmware: Rename tagipv6 to tag
    Now that some of the old functionality is gone, we can
    rationalise some of the naming. The only useful tag mode
    should now be called tag, as we're no longer preserving
    backwards compatibility with the older development modes.
    [cli.c]
2019-03-23 firmware: First stab at double buffering and multiple receive
    tag_two_way is now obsolete, replaced by new controls:
    tag_max_anchors - Maximum number of ranging request
    packets to process
    tag_min_responses - Minimum number of ranging response
    packets to send
    Typical use cases:
    OWR1 - max_anchors = 0, min_responses = 0
    OWR2 - max_anchors = 0, min_responses = 1
    TWR1 - max_anchors = 1, min_responses = 0
    TWRn - max_anchors = n, min_responses = 0
    TWRn + OWR2 - max_anchors = n, min_responses = 1
    This code is untested so far, so is likely to be full of bugs
    [config.h, main.c]
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2019-04-24 firmware: Config reset/enumerate/read (plus misc battery things)
    This is a first implementation of an unencrypted version of
    config requests reset, enumerate and read. Hooks are in place to
    add the crypto when it's ready.
    This commit also includes things that accidentally weren't committed
    before they got tangled up in these changes:
    * Increased battery full threshold
    * Flat battery handling (implemented, but currently disabled)
    * Command to read battery state
    * Only send battery state if valid
    * Debug output on startup to show reset cause
    [battery.c, cli.c, main.c]
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2019-04-25 firmware: Time the rx window from the start, not from the last restart
    We need to use a timer on the microcontroller for this, as the radio is
    not capable of using its rx timeout functionality in this way. So we
    just disable the rx timeout on the radio and take care of it ourselves.
    This is non-trivial because there is no fast accurate clock on the
    microcontroller. The system is clocked from an RC oscillator, which
    could be off by varying amounts depending on the environment.
    So, we estimate the time based on the nominal frequency and then
    dynamically adjust the time based on the actual time of the previous
    window, measured by reading timestamps from the dw1000.
    Currently there's no filte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
    [main.c]
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2019-04-30 case: Thinner wall and slight tweaks
    We can get away with a 1.5mm wall thickness. This
    saves 1mm overall, and significantly improves the feel
    of the tag.
    [case.FCStd]
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2019-05-03 firmware: implement OTA write
    This implements OTA write. There must be sufficient space
    available in config for the entire write to complete, otherwise
    it is rejected. An extra deletion step is done prior to the writes
    so that the config won't temporarily exceed capacity, but only if
    the data needs changing.
    A few bugs in the config module have been fixed along the way.
    Also some new cli commands:
    * free - returns the free space available in the config area
    * dump - dumps the internal data structure of the config area
    [cli.c, config.h]
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2019-05-03 circuit: Add UART-USB level shifting and reduce charge current
    We need to connect the UART to the USB data pins. As these will present
    5 volts, we need to add level shifting to protect the 3.3 volt mcu.
    We will need to enable the internal pullup on the UART Rx line.
    The host cable we are proposing to use already has a pullup on its
    Rx line.
    While we're here, reduce the charge current to just under 200mA in
    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
    [tail.sch]
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2019-05-22 bootloader: fix line endings
    [boot.c, bootloader.c, config.h]
2019-05-22 firmware: Disable unsafe functionality and shrink app area
    We don't want the bootloader to touch the config area - that's
    managed by the firmware.
    We also don't want the ability to brick the chip in the field
    by mistying, so disable the debug lock functionality (which may
    or may not work anyway, as we've changed the pin assignments).
    [bootloader.c, config.h]
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2019-05-23 tester: swap jtag and uart
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2019-06-06 case: Fix screw hole diameter
    The screw holes were using ScrewRadius instead of ScrewHoleRadius.
    [case.FCStd]
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2019-06-06 firmware: optionally tristate
    This also adds a config option, uart_drive.
    This config option can be set to 1 to avoid tristating the UART, which allows
    the use of cables without a pullup.
    [config.h, main.c]
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2019-06-13 firmware: Delay the start of the receive window
    A new config key, rxdelay, configures the time (in the same
    units as rxtimeout) for which to delay the start of the receive
    window.
    Note that because of the use of delayed reception, there is a
    minimum value for this parameter which must be determined
    experimentally and may vary as the firmware changes. It is
    currently a little under 700 microseconds. If set too low,
    the firmware will fail to open the receiver at all.
    Also note that the timer used to implement this feature
    is only a 16 bit timer and excessively large values of
    this parameter (or rxtimeout, as value approximately
    based on the sum of these parameters is timed) will
    cause the ti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
    [cli.c, config.h, main.c]
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2019-06-13 firmware: Correct temperature calculation formula
    The datasheet had an error in the formula for calculating
    the temperature from the ADC readings, where it suggested
    multiplying by 1.14 instead of dividing by 1.14.
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2019-06-14 firmware: add jitter blink
    [config.h]
2019-06-14 firmware: Don't print reset cause number as well as text
    [main.c]
2019-06-17 config: add jitter
    [utrack-config.txt]
2019-06-17 scripts: send.sh: Don't echo what the tag sends back to it
    For some reason linux has been echoing data from the tag back
    to the tag on the UART. This doesn't seem to have been the case
    when developing or demonstrating this script previously, but
    it has shown to be a problem on at least two people's laptops today.
    So we explicitly turn off echo.
2019-07-04 prodtest2a: design proper PCB
    This integrates the relay functionality as well as the tester
    onto a single PCB, designed to fit within an instrument enclosure.
    Custom front and rear panels will need to be manufactured, probably
    by 3D printing, to match this layout.
    It is intended that the fixed test hardware will be connected to the
    back panel, and that the DUT (via the jig) will be connected to the
    front panel.
    [prodtest2a.kicad_pcb, prodtest2a.sch]
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2019-07-24 firmware: Debug events and time debug
    This commit adds two new commands:
    events - display a number which should be zero but indicates
    that some sanity check has failed otherwise
    time - display current time, early wakeup advance and
    timer table (relative to current time).
    In order to prevent false triggering of time-related debug
    events, also explicitly avoids scheduling events in the past
    while processing accelerometer triggers.
    [cli.c, main.c]
2019-07-25 firmware: new sanity check, and abort transmit if sanity check fails
    New sanity check to make sure that the radio is not actually asleep when
    a blink is started.
    Also, now abort the blink event if a relevant sanity check fails, rather
    than powering on through.
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2019-07-25 firmware: collect entropy
    Collect entropy, feed it to the RBG, and log failures of run-time tests of
    entropy quality.
    [main.c]
2019-07-26 firmware: Add supervisor to check for failed blink events
    We add a 100ms timer starting at each blink event. If the
    radio is still active when this times out, it is assumed
    that something has gone wrong. We capture the DW1000 state
    register to aid debugging, and record the number of times
    that this condition has occurred. These values can be
    read with the "supervisor" command. If the count is non-zero
    then we will also start transmitting an IE containing
    these values.
    When we do hit this condition, we also send TRXOFF to the
    radio and set radio_active to false, in the hope that
    this will be sufficient to unblock the radio and allow
    the firmware to continue at the next blink event.
    It may b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
    [cli.c]
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2019-11-05 prodadapterb3: Move tester connectors to avoid cable twisting
    In order to provide a more straight through approach, the tester
    side connectors are placed on the back of the PCB. This allows the
    cables to be connected without any twisting, as well as simplifying
    the PCB routing.
    [prodadapterb3.kicad_pcb]
2019-11-06 firmware: transmit cookies
    Transmit 'cookies' (an IV precursor) if sufficient entropy is available on the
    tag and tx_cookie is set to true in the tag config.
    This patch includes explicit alignment of byte arrays that are cast to
    uint32_t* in emlib. The CPU is configured to halt on unaligned access.
    This also contains DRBG fixes (calling AES_ECB128 with lengths of 16 bytes).
    This also contains code to calculate an IV from the cookie, using the
    appropriate derived key. This has been verified against the Python server
    implementation.
    [config.h, main.c]
2019-11-07 prodadapterb3: Swap SCA and SCL (oops!)
    [prodadapterb3.kicad_pcb, prodadapterb3.sch]
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2019-12-16 tester: Fixes to device tree on adapter
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
